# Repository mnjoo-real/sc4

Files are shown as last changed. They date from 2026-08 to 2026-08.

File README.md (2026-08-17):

# Singing capacitor — pre-experiment numerical model

## PCB ordering — start here

A validated PCB fabrication package for all 5 board variants exists under
[`pcb/`](pcb/). This section is a navigation index only — the files linked
below are the source of truth; nothing here duplicates their content.

**Start here:**
[`pcb/v0.3.1_FABRICATION_PACKAGE_SUMMARY.md`](pcb/v0.3.1_FABRICATION_PACKAGE_SUMMARY.md)

This is the top-level summary of the current PCB fabrication package and
records whether each board variant has passed the required KiCad/DRC/
Gerber/drill/visual checks.

For detailed per-board validation — including the authoritative
`READY_FOR_JLCPCB` status for each variant — see
[`pcb/FABRICATION_REVIEW.md`](pcb/FABRICATION_REVIEW.md). **Only order a
board whose entry there is marked ready.**

### The five board variants

    S90-0402
    S90-0603
    S90-0805
    W90-0603
    S0-0603

### Where the actual files are, per variant

| what | where | for |
|---|---|---|
| Editable KiCad source | `pcb/<variant>/<variant>.kicad_pcb` | opening/editing in KiCad |
| Raw Gerber + drill files | `pcb/<variant>/manufacturing/gerbers/` | inspection, not direct upload |
| **JLCPCB upload archive** | `pcb/<variant>/manufacturing/<variant>_JLCPCB_Gerber.zip` | **upload this to JLCPCB** |
| Gerber verification images | `pcb/<variant>/manufacturing/gerber_verification/` | checking the export against the design before ordering |
| KiCad 3D renders | `pcb/<variant>/renders/` | visual sanity-check, not fabrication input |

**The `*_JLCPCB_Gerber.zip` file is the file to upload to JLCPCB.** Do not
upload the `.kicad_pcb`/`.kicad_pro` source files, the PNG renders, or the
DRC/validation reports — those are for review, not fabrication input.

The five current upload archives:

- [`pcb/S90-0402/manufacturing/S90-0402_JLCPCB_Gerber.zip`](pcb/S90-0402/manufacturing/S90-0402_JLCPCB_Gerber.zip)
- [`pcb/S90-0603/manufacturing/S90-0603_JLCPCB_Gerber.zip`](pcb/S90-0603/manufacturing/S90-0603_JLCPCB_Gerber.zip)
- [`pcb/S90-0805/manufacturing/S90-0805_JLCPCB_Gerber.zip`](pcb/S90-0805/manufacturing/S90-0805_JLCPCB_Gerber.zip)
- [`pcb/W90-0603/manufacturing/W90-0603_JLCPCB_Gerber.zip`](pcb/W90-0603/manufacturing/W90-0603_JLCPCB_Gerber.zip)
- [`pcb/S0-0603/manufacturing/S0-0603_JLCPCB_Gerber.zip`](pcb/S0-0603/manufacturing/S0-0603_JLCPCB_Gerber.zip)

### Before ordering — read in this order

1. [`pcb/v0.3.1_FABRICATION_PACKAGE_SUMMARY.md`](pcb/v0.3.1_FABRICATION_PACKAGE_SUMMARY.md) — current fabrication-package summary.
2. [`pcb/FABRICATION_REVIEW.md`](pcb/FABRICATION_REVIEW.md) — detailed per-board validation, `READY_FOR_JLCPCB` status, and the Gerber/drill/render file map.
3. [`design/jlcpcb_order_settings.csv`](design/jlcpcb_order_settings.csv) — the JLCPCB fabrication options to select on the quote/order page (material, layers, thickness, copper weight, surface finish, etc.).
4. [`design/pcb_quantity_plan.csv`](design/pcb_quantity_plan.csv) — planned bare-PCB order quantities, per variant.
5. [`design/board_population_plan.csv`](design/board_population_plan.csv) — how the ordered boards are intended to be populated with MLCCs for the experiment.
6. [`design/PCB_FABRICATION_SPEC.md`](design/PCB_FABRICATION_SPEC.md) — detailed fabrication/design rationale and the common board specification.
7. [`design/PCB_CAD_ASSUMPTIONS.md`](design/PCB_CAD_ASSUMPTIONS.md) — fabrication/CAD parameters not originally fixed in v0.3.0, and the assumptions/fixes made while generating the KiCad files.

**⚠ Quantity check before the final order:** `pcb_quantity_plan.csv` is the
order-quantity source; `board_population_plan.csv` is the specimen
population source, and should be checked against it before the final
purchase. As of this writing they **do not agree for S90-0603**:
`board_population_plan.csv` calls for 15 populated S90-0603 specimens
(R×3, C1×2, C2×2, V1×2, V2×2, V3×2, N1×2), but
`pcb_quantity_plan.csv` currently plans to order only 5 S90-0603 boards.
The other four variants (S90-0402, S90-0805, W90-0603, S0-0603) agree
(5 planned = 5 needed each). Before placing the final order, verify that
the fabrication quantity plan covers the specimen population plan — this
README does not resolve that inconsistency, and the quantity was not
guessed here.

### Placing the order

1. Open `pcb/v0.3.1_FABRICATION_PACKAGE_SUMMARY.md`.
2. Confirm the desired board is marked ready in `pcb/FABRICATION_REVIEW.md`.
3. Open `design/jlcpcb_order_settings.csv`.
4. Open `design/pcb_quantity_plan.csv` (and cross-check against
   `board_population_plan.csv` per the warning above).
5. Upload that variant's `*_JLCPCB_Gerber.zip` to JLCPCB.
6. Confirm that JLCPCB correctly detects the board (outline, layer count,
   size).
7. Apply the fabrication options from `jlcpcb_order_settings.csv`.
8. Set the quantity from the current quantity plan.
9. Inspect the online Gerber preview (checklist below).
10. Only then proceed to fabrication/payment.

`design/jlcpcb_order_settings.csv` remains the source of truth for the
actual option selections — the JLCPCB UI's exact labels aren't reproduced
here.

### What to check in the JLCPCB Gerber viewer

Before paying, visually compare JLCPCB's preview against this repository's
verified artifacts and confirm, at minimum:

- board outline appears correct,
- four mounting holes are present,
- the MLCC footprint is present at the intended position,
- S90 vs. S0 orientation is visibly different where intended,
- top copper traces are present,
- there is no unexpected bottom copper,
- solder-mask openings are present over the intended pads,
- no obvious trace or outline is missing.

Reference images for this comparison:

- `pcb/<variant>/manufacturing/gerber_verification/` — most relevant for
  fabrication inspection, since these are rendered directly from the
  exported Gerbers:
  `<variant>_composite_top.png`, `<variant>_top_copper.png`,
  `<variant>_solder_mask.png`, `<variant>_silkscreen.png`,
  `<variant>_edge_cuts.png`
- `pcb/<variant>/renders/` — real KiCad top/bottom/perspective 3D renders
  (useful, but decorative relative to the Gerber-verification images above)
- [`pcb/PCB_5_VARIANT_COMPARISON.png`](pcb/PCB_5_VARIANT_COMPARISON.png) — all five variants at the same scale, for a quick overview

### Bare PCB vs. assembly

The `*_JLCPCB_Gerber.zip` files are **PCB fabrication files only**.
Uploading one orders a **bare PCB** — MLCC assembly is **not** included.
See [`design/board_population_plan.csv`](design/board_population_plan.csv)
for the intended capacitor population per board. Assembly (PCBA) is a
separate deliverable, not covered by this package.

### Directory map

```
pcb/
├── v0.3.1_FABRICATION_PACKAGE_SUMMARY.md
├── FABRICATION_REVIEW.md
├── PCB_5_VARIANT_COMPARISON.png
├── S90-0402/
│   ├── S90-0402.kicad_pcb
│   ├── manufacturing/
│   │   ├── S90-0402_JLCPCB_Gerber.zip   <- upload this to JLCPCB
│   │   ├── gerbers/
│   │   ├── drc_report.txt
│   │   ├── drill_report.txt
│   │   └── gerber_verification/
│   └── renders/
├── S90-0603/
├── S90-0805/
├── W90-0603/
└── S0-0603/
```

```
design/
├── jlcpcb_order_settings.csv
├── pcb_quantity_plan.csv
├── board_population_plan.csv
├── PCB_FABRICATION_SPEC.md
└── PCB_CAD_ASSUMPTIONS.md
```

---

A lightweight simulation for planning a *singing capacitor* experiment before
ordering the PCB and MLCCs.

The goal is **not** to predict the exact sound level of a commercial capacitor.
Instead, the model is used to decide:

- what PCB size and thickness to order,
- where to place the MLCC on the PCB,
- which orientation to use,
- what frequency range to sweep,
- and which conditions should produce a strong or weak vibration response.

The model deliberately keeps only the physics needed for those design choices.

---

## 1. The physics being modelled

A Class-II ceramic MLCC such as X5R or X7R deforms when an electric field is
applied. The first-order electromechanical model is

    S = dE + M E²

where `S` is strain, `d` is the piezoelectric coefficient, `M` is the
electrostrictive coefficient, and `E` is the electric field.

For

    E(t) = E_DC + E_AC cos(ωt)

the strain contains two important vibration components:

    A₁ cos(ωt),        A₁ = (d + 2 M E_DC) E_AC
    A₂ cos(2ωt),       A₂ = ½ M E_AC²

so an electrical excitation at frequency `f` can mechanically excite the PCB
at both

    f          fundamental
    2f         second harmonic

The second harmonic is important because it can hit a PCB resonance even when
the electrical excitation frequency itself does not.

For the first version of the simulation, the exact `d` and `M` of a commercial
MLCC are **not required**. The capacitor is treated as a relative vibration
source with configurable strengths at `f` and `2f`.

### PCB resonance

The PCB is approximated as a rectangular thin plate.

Its bending rigidity is

    D = E h³ / [12(1 − ν²)]

where `E` is the effective Young's modulus of the PCB, `h` is PCB thickness,
and `ν` is Poisson's ratio.

For a simply supported rectangular plate with length `a` and width `b`,

    φ_mn(x,y) = sin(mπx/a) sin(nπy/b)

and the natural frequencies are

    ω_mn = π² √(D / ρh) · (m²/a² + n²/b²)

    f_mn = ω_mn / 2π

This is not intended to reproduce a real clamped PCB exactly. It is sufficient
for finding the main trends:

- a larger PCB gives lower resonant frequencies,
- a thicker PCB gives higher resonant frequencies,
- different MLCC positions couple differently to each mode.

### MLCC position and orientation

The MLCC does not excite every PCB mode equally.

For a simple point-force source,

    coupling ∝ φ_mn(x_c, y_c)

so a capacitor near a modal antinode excites that mode strongly, while one near
a node excites it weakly.

The soldered MLCC also acts approximately like a small force couple / moment.
For that case the coupling is related to the slope of the mode shape:

    x-oriented MLCC:  coupling ∝ ∂φ_mn/∂x
    y-oriented MLCC:  coupling ∝ ∂φ_mn/∂y

This is why rotating the same MLCC by 90° can change the PCB vibration.

The simulation therefore focuses on the chain

    voltage
      ↓
    relative MLCC source at f and 2f
      ↓
    PCB mode coupling
      ↓
    PCB vibration response

rather than trying to model every internal ceramic layer.

---

## 2. What the code actually does

### MLCC source (`source.py`)

The capacitor is represented by two harmonic source components:

    source_f  = C₁ · A₁
    source_2f = C₂ · A₂

For the initial model, `C₁` and `C₂` are simply configurable scale factors.

If real electromechanical coefficients are unavailable, the code can instead
use normalized source strengths such as

    source_f  = 1
    source_2f = r_harmonic

so PCB design can be studied independently of the uncertain absolute MLCC
vibration amplitude.

The important output is therefore **relative response**, not absolute SPL.

### PCB (`plate.py`)

The PCB is an isotropic rectangular thin plate with configurable

    length
    width
    thickness
    Young's modulus
    density
    Poisson ratio
    damping

The code computes the first several `(m,n)` modes analytically.

The default reference geometry is the one used in Kim et al. (2019):

    100 mm × 40 mm × 1.0 mm

This is only a baseline. The simulation sweeps several nearby geometries to find
a board that has clear resonances in the experimental frequency range.

### Coupling (`coupling.py`)

For each candidate MLCC position and orientation, the code evaluates how
strongly the source couples to every PCB mode.

The main scan is

    x/a = 0.20, 0.35, 0.50, 0.65, 0.80
    y/b = 0.25, 0.50, 0.75
    orientation = 0°, 90°

This produces both

- a **high-coupling position** for a clear singing-capacitor demonstration,
- and a **low-coupling position** that can be used as a control.

### Frequency response (`response.py`)

Each PCB mode is treated as a damped harmonic oscillator:

    q_n(ω) =
        Q_n /
        [m_n(ω_n² − ω² + i 2ζ_n ω_n ω)]

The modal responses are summed to obtain relative PCB displacement and velocity.

The simulation evaluates the response at both

    f
    2f

for each electrical excitation frequency.

The main plotted quantity is PCB velocity amplitude, used only as a
**vibration / acoustic-noise proxy**.

No acoustic radiation model is included.

### Sweep (`run_sweep.py`)

The first design sweep varies

    PCB length       60, 80, 100 mm
    PCB width        30, 40 mm
    PCB thickness    0.8, 1.0, 1.6 mm

and scans excitation frequencies over

    200–3000 Hz

with a coarse step first, followed by a finer scan near predicted resonances.

After the PCB geometry is selected, the code scans MLCC position and orientation.

The simulation is therefore used in this order:

    1. choose PCB geometry
    2. find PCB resonances
    3. choose MLCC position
    4. compare 0° and 90° orientation
    5. choose useful excitation frequencies
    6. define strong-response and weak-response experimental conditions

---

## 3. Validation (`test_model.py`)

The model only needs simple checks because it is an experiment-design tool, not
a high-fidelity FEM solver.

| check | expected result |
|---|---|
| increasing PCB length | resonant frequencies decrease |
| increasing PCB thickness | resonant frequencies increase |
| mode shape at supported edge | approximately zero |
| MLCC placed at a modal node | weak point-force coupling |
| MLCC placed at an antinode | strong point-force coupling |
| rotate MLCC by 90° | x/y moment coupling changes |
| increase damping | resonance peak becomes lower and broader |
| electrostrictive source | response can appear at `2f` |

The code should also reproduce the analytical strain amplitudes

    A₁ = (d + 2 M E_DC) E_AC
    A₂ = ½ M E_AC²

for a synthetic test case.

Synthetic coefficients are used only to check the equations; they must not be
presented as properties of a real commercial MLCC.

---

## 4. Outputs

### `fig1_modes.png`

The first PCB mode shapes and their natural frequencies for the baseline

    100 × 40 × 1 mm

board.

This shows which PCB modes lie inside the planned excitation range.

### `fig2_geometry_sweep.png`

Predicted resonant frequencies for different PCB sizes and thicknesses.

This is the main figure for deciding **which PCB to order**.

A useful board should have:

- at least a few resonances inside the measurable frequency range,
- resonances separated enough to identify experimentally,
- and no extreme sensitivity to small geometry changes.

### `fig3_frequency_response.png`

Relative PCB vibration versus electrical excitation frequency.

Both mechanical components are shown:

    response at f
    response at 2f

A strong peak occurs when either `f` or `2f` approaches a PCB resonance.

This figure determines which frequency ranges should be scanned more densely in
the real experiment.

### `fig4_position_map.png`

Heatmap of predicted vibration versus MLCC position.

This is used to choose

- one high-response capacitor location,
- one low-response control location.

### `fig5_orientation.png`

Comparison of the same MLCC position at

    0°
    90°

to determine whether orientation should be included as an experimental variable.

### `recommended_setup.csv`

Final summary produced by the sweep:

| parameter | recommended value |
|---|---|
| PCB length | simulation result |
| PCB width | simulation result |
| PCB thickness | simulation result |
| MLCC x-position | simulation result |
| MLCC y-position | simulation result |
| MLCC orientation | simulation result |
| main frequency range | simulation result |
| resonance frequencies | simulation result |
| strong-response condition | simulation result |
| control condition | simulation result |

The code should not fill this table with hard-coded recommendations. Values are
written only after the sweep has been run.

---

## 5. Running it

```bash
pip install numpy scipy matplotlib pandas

python test_model.py
python run_modes.py
python run_sweep.py geometry
python run_sweep.py position
python run_sweep.py all
```

All figures and tables are written to

```text
out/
```

Suggested repository structure:

```text
singing-capacitor/
│
├── README.md
├── model.py
├── source.py
├── plate.py
├── coupling.py
├── response.py
├── test_model.py
├── run_modes.py
├── run_sweep.py
└── out/
```

The main parameters should be collected in one dataclass:

```python
from dataclasses import dataclass

@dataclass
class Params:
    pcb_L: float = 0.100
    pcb_W: float = 0.040
    pcb_h: float = 0.001

    E_pcb: float = 20e9
    rho_pcb: float = 1850.0
    nu_pcb: float = 0.13
    damping: float = 0.02

    mlcc_x_frac: float = 0.50
    mlcc_y_frac: float = 0.50
    orientation_deg: float = 0.0

    f_min: float = 200.0
    f_max: float = 3000.0
```

The exact effective FR-4 material constants are uncertain, so these values are
configuration parameters rather than fixed physical truths.

---

## 6. Known limitations — worth stating in a report

* The PCB is an **isotropic simply supported thin plate**. A real FR-4 PCB is
  anisotropic and the experimental bolts/clamps change its natural frequencies.
  The model should therefore be used for geometry selection and qualitative
  trends, not exact resonance prediction.

* The MLCC is represented as a **lumped harmonic source**, not as hundreds of
  dielectric and electrode layers. This is deliberate: the purpose is to choose
  the experimental PCB and setup before the exact commercial MLCC properties
  are known.

* Exact piezoelectric and electrostrictive coefficients of commercial MLCCs are
  usually unavailable. Unless experimentally measured values are supplied, the
  simulation should compare **relative source amplitudes**, not claim absolute
  capacitor vibration.

* Solder geometry is not explicitly modelled. Its effect is absorbed into the
  equivalent source / moment coupling.

* The first model does not calculate sound pressure. PCB velocity is used as a
  proxy for how strongly the board is likely to radiate sound.

* Absolute resonance frequencies will shift after the real PCB is manufactured
  and mounted. After the first PCB is measured, the effective material and
  damping parameters can be calibrated and the simulation rerun.

---

## 7. What this simulation must decide before ordering

The model is successful if it answers these practical questions:

1. Should the PCB be approximately `60`, `80`, or `100 mm` long?
2. Should its thickness be `0.8`, `1.0`, or `1.6 mm`?
3. Which resonances fall inside the planned excitation range?
4. Where should the MLCC be soldered for a strong response?
5. Where should a control MLCC be soldered for a weak response?
6. Does rotating the MLCC by 90° produce a useful difference?
7. Which electrical frequencies should be scanned densely in the real test?
8. Is the response dominated by the fundamental `f`, the second harmonic `2f`,
   or both?

Once these are answered, the PCB can be ordered and the detailed MLCC
comparison can be designed around the selected board.

The key principle is:

    keep the model only as complicated as necessary
    to make the experimental setup decision.

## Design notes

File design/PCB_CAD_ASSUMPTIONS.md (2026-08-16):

# PCB CAD assumptions — v0.3.1

This lists every fabrication parameter that v0.3.0 (`design/PCB_FABRICATION_SPEC.md`,
`design/pcb_variants.csv`, `design/pcb_coordinates.csv`) left unspecified,
and the assumption `pcb/generate_pcb.py` used to fill it in, per the task
instruction: *"do not silently treat a new assumption as an existing v0.3.0
decision."* Each item below is tagged **[v0.3.0, existing]** if it was
already fixed by earlier design docs, or **[v0.3.1, new assumption]** if
this stage introduced it.

No inconsistency was found between the task brief's stated common
specification / MLCC placement table and `pcb_variants.csv` /
`pcb_coordinates.csv` — they match exactly, so nothing was silently
changed.

## Environment constraint (read first)

**KiCad is not installed in this environment** (checked: no `kicad-cli` on
PATH, no `pcbnew` Python module, no `/Applications/KiCad*`, not found via
`brew`). This affects every assumption below: none of these `.kicad_pcb`
files have been opened, parsed, or DRC'd by real KiCad. See
`pcb/FABRICATION_REVIEW.md` for exactly what was and wasn't possible to
verify as a result.

## 1. Edge interface pad **center coordinates** — existing, reused

**[v0.3.0, existing]**. `PCB_FABRICATION_SPEC.md` section 5 already gives a
"suggested reference pad row" at x=5mm, y = 12.5 / 17.5 / 22.5 / 27.5 mm for
DRIVE+ / SENSE+ / SENSE- / DRIVE- respectively (marked "to be confirmed in
EDA, not final" — but it is a value, not a gap). This implementation treats
those coordinates as the thing to implement, per the task's own instruction
that its preferred default applies only *"if no value is already
specified."* The generator's `EDGE_PAD_X` / `EDGE_PADS` constants match this
table exactly.

## 2. Edge interface pad **shape and diameter** — new assumption

**[v0.3.1, new assumption]**. v0.3.0-C fixed the pad *centers* but never a
shape or size. This was genuinely open, so the task's stated preferred
default was used: **round, 2.5 mm diameter**, exposed copper (ENIG) with no
solder-mask covering, no paste layer (hand-soldered wire lead, not a
reflow part). Implemented as `EdgeContact_2.5mm_Round` in
`pcb/SC4.pretty/`.

## 3. Exact trace routing geometry — new assumption

**[v0.3.1, new assumption]**. v0.3.0-C fixed trace *widths* (0.5 mm drive,
0.2 mm sense) and the *topological* rule (SENSE traces must originate
directly at the MLCC pad copper, not tap the DRIVE trace) but never a
routed path. This implementation uses the simplest routing that satisfies
that rule without producing an unintended short:

- Each of the 4 nets gets its own dedicated staging x-lane (`mlcc_x - 8`
  through `mlcc_x - 5`, one per net) so no two different-net segments ever
  run parallel/collinear.
- For 90 deg boards (S90-*, W90-0603), each trace is a simple 3-segment
  L-route: edge pad -> its staging lane -> the target MLCC pad's row ->
  straight into the pad. No detour is needed because the two MLCC pads
  differ only in y, and each net's staging lane already sits at a distinct
  y before converging.
- For the 0 deg board (S0-0603), the two MLCC pads differ only in x, so a
  trace headed for the farther pad would otherwise have to cross straight
  through the nearer pad's copper. Only for this case, the SENSE-/DRIVE-
  pair detours above the nearer pad (`mlcc_y + pad_height/2 + 0.3 mm`
  clearance) before dropping onto the far pad. This is the "extra
  complexity only where necessary" the task asked for — the 90 deg boards
  do not need it.
- `pcb/validate_pcb.py` checks geometrically that no two different-net
  F.Cu segments touch or cross anywhere except at their one legitimate
  shared point (the MLCC pad itself).

## 4. DRIVE+/SENSE+ and DRIVE-/SENSE- net topology — new assumption, explicit trade-off

**[v0.3.1, new assumption]**. This is the most consequential CAD decision
in this package, so it's called out on its own.

A 4-wire/Kelvin connection means DRIVE+ and SENSE+ are, by design,
electrically the *same node* — they are both wired straight to the MLCC's
+ terminal with nothing in between; that's what makes it "4-wire" (the
DRIVE path carries current, the SENSE path carries ~none, so IR drop in the
DRIVE trace doesn't corrupt what SENSE reads). A PCB tool's "net" is
defined as a connectivity group, so representing DRIVE+ and SENSE+ as two
different net objects that are also physically joined at the MLCC pad is,
strictly, the same thing electrically — the question is only how to encode
it in KiCad's file format.

KiCad has a purpose-built feature for exactly this ("net ties": a
footprint attribute, `net_tie_pad_groups`, that lets two named nets touch
at one defined point without DRC treating it as a short elsewhere). That
would let this design keep 4 distinctly-named nets. **It was not used
here**, because its exact file-format syntax could not be verified without
a working KiCad installation, and getting it wrong risks producing a file
that fails to parse in KiCad at all — a worse outcome than a
syntactically-safe simplification.

Instead: **DRIVE+ and SENSE+ share one KiCad net (`DRIVE_SENSE_PLUS`), and
DRIVE- and SENSE- share one KiCad net (`DRIVE_SENSE_MINUS`)**. This is
electrically identical to the intended Kelvin topology. The 4 external
pads remain individually and correctly labeled (`DRIVE+`, `SENSE+`,
`SENSE-`, `DRIVE-` as each edge-contact footprint's reference designator)
and are routed as 4 physically separate, non-touching copper traces (see
item 3) — only the *net name* is merged, not the copper layout.

**Consequence for the validation requirement** "all four interface nets
reach the intended MLCC terminal": this is verified as *connectivity*
(each of the 4 labeled pads reaches the correct terminal's copper), not as
4 distinct KiCad net objects — there are 2. If true 4-distinct-net
modeling via KiCad net ties is wanted, that is a follow-up task for someone
with a working KiCad installation to implement and verify; it would not
change any board geometry, only the netlist representation.

## 5. Which MLCC pad is the "+" terminal — new assumption

**[v0.3.1, new assumption]**. The MLCC is a non-polarized ceramic capacitor
— "+"/"-" is a labeling convention for this design, not a real polarity.
Convention used: for 90 deg boards, the pad at the *smaller* y (closer to
the DRIVE+/SENSE+ side of the edge row) is "+"; for the 0 deg board, the
pad at the *smaller* x (nearer the edge, i.e. pad1 in `pcb_coordinates.csv`)
is "+". This keeps routing short and simple; it has no effect on the
experiment (the model treats the MLCC as an unpolarized source).

## 6. MLCC footprint pad size / pitch — existing, reused

**[v0.3.0, existing]**. Taken directly from `PCB_FABRICATION_SPEC.md`
section 4's nominal IPC-7351 table (0402: 0.6x0.6mm pads / 1.0mm pitch;
0603: 0.9x1.0mm / 1.6mm; 0805: 1.2x1.45mm / 1.9mm) and
`pcb_coordinates.csv`'s computed pad centers. Not re-derived here.

## 7. Silkscreen content and placement — new assumption, deliberately conservative

**[v0.3.1, new assumption]**. `PCB_FABRICATION_SPEC.md` section 7 permits
*only* "board/variant identification silkscreen (e.g. 'S90-0603', a rev
letter)" in the edge strip, and forbids non-essential silkscreen in the
active region entirely. This implementation:

- Prints only the variant name (e.g. `S90-0603`) as silkscreen text, at a
  single position (x=5, y=31mm) chosen to clear both the edge-pad column
  (which ends at y=27.5+1.25=28.75mm) and the top mounting hole's keepout
  (which starts at y=35-1.6=33.4mm) — this position is identical across
  all 5 variants since the edge row geometry doesn't vary by variant.
- Does **not** silkscreen individual pad-function labels (DRIVE+, SENSE+,
  etc.) next to each pad, even though there was room — the spec only
  explicitly allows variant/rev identification, and adding more was judged
  to be overstepping v0.3.0-C rather than implementing it.
- Hides the reference/value silkscreen KiCad normally auto-generates for
  every footprint (MLCC and all 4 mounting holes), since two of the four
  mounting holes (at x=95mm) and the MLCC itself sit in the active region
  (x>15mm) where that silkscreen would be disallowed.

## 8. Board stackup / manufacturing defaults not otherwise specified

**[v0.3.1, new assumption]**, using generic, non-consequential defaults
since v0.3.0 explicitly left these to "manufacturer default" /
open-at-order-time (`jlcpcb_order_settings.csv`):

- Solder-mask-to-copper clearance: 0.05 mm (generic default).
- 2-layer stackup with F.Cu/B.Cu both defined (required by the file
  format) but zero copper features ever placed on B.Cu.

## 9. Coordinate system note (not an assumption about the design, a KiCad-mechanics note)

The design docs use origin = bottom-left, x/y both increasing "up/right".
KiCad's own on-screen Y axis increases downward by default. This
implementation stores every coordinate's numeric value exactly as given in
`pcb_coordinates.csv` / the task brief as KiCad's literal (x, y) — it does
not attempt to flip anything to "look" correct on screen. This has no
effect on manufactured geometry (hole spacing, MLCC-to-hole relationships,
and silkscreen orientation are all self-consistent within the file), but
means a human opening these files in KiCad should confirm orientation by
reading the printed variant-ID silkscreen text and cross-checking numeric
coordinates (KiCad's Properties panel), not by assuming screen "up" means
larger y.

## Summary table

| item | status |
|---|---|
| Board outline, thickness, layer count, copper weight, finish | v0.3.0, existing |
| Mounting hole coordinates and diameter | v0.3.0, existing |
| MLCC center coordinates and orientation, per variant | v0.3.0, existing |
| MLCC footprint pad size/pitch, per package | v0.3.0, existing |
| Edge interface pad center coordinates | v0.3.0, existing |
| Drive/sense trace widths | v0.3.0, existing |
| Edge interface pad shape/diameter | v0.3.1, new (task default: round 2.5mm) |
| Exact trace routing path | v0.3.1, new |
| DRIVE+/SENSE+ and DRIVE-/SENSE- net topology (merged vs. net-tie) | v0.3.1, new, explicit trade-off |
| "+"/"-" terminal labeling convention | v0.3.1, new (arbitrary, no experimental effect) |
| Silkscreen content/placement | v0.3.1, new, deliberately minimal |
| Solder mask clearance and other fab-default values | v0.3.1, new, non-consequential |

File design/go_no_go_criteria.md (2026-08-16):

# Go/no-go criteria — v0.3.0-E

**Placement**: after Phase 1 (reference position/orientation validation),
before Phase 2 (start of the full capacitor-property dataset). See
`experiment_phases.md`.

## The three checks

Per the design brief: do not proceed to the full capacitor-property dataset
(Phases 2-8) if there is no reproducible PCB resonance, no reproducible
position effect, and no reproducible orientation effect.

**Interpretation note**: this design treats the three checks as
independently gating — a "no-go" on *any one* of them is sufficient to stop
(standard practice for a validation gate: an experiment shouldn't proceed to
a full comparison campaign if any one of its foundational assumptions
hasn't checked out, even if the other two look fine). If a stricter reading
was intended (stop only if *all three* simultaneously fail), that changes
the gate significantly and should be corrected explicitly — flagging it here
rather than silently picking one.

### 1. Reproducible PCB resonance

- Phase 0 (S90-0603-R-01) establishes fr1, fr2, fr3 from a full broad sweep.
- Phase 1 does not repeat a full broad sweep on every other specimen (see
  `experiment_phases.md`). Instead, treat resonance as reproducible if the
  other two S90-0603-R specimens (R-02, R-03) show a clear, elevated
  acoustic response at or near fr1, fr2, and fr3 (the same set points
  already being measured in Phase 1's standard six-frequency set) relative
  to that session's background-noise floor.
- **Suggested check** (adjust to the noise floor actually observed —
  this number is a starting point, not a value given in the design brief):
  peak acoustic amplitude at each of fr1/fr2/fr3 is at least ~6 dB above
  the session's background-noise recording, for both R-02 and R-03.
- **No-go** if R-02 or R-03 shows no such elevated response at the expected
  set points (suggesting the resonance seen on R-01 was a one-off, not a
  property of the board design).

### 2. Reproducible position effect

- Compare S90-0603-R-01/02/03 (strong position) against
  W90-0603-R-01/02/03 (weak/control position) at the standard condition
  (0.10 V_peak, 0 V, standard six-frequency set).
- **Go** if S90 response is consistently higher than W90 response across the
  replicate pairs (matching the predicted ~4.9x strong/control ratio
  direction from `out/final_pcb_recommendation.txt` — the magnitude is a
  simulation guide only, not a pass/fail threshold; only the *direction and
  consistency* of the effect is being checked here).
- **No-go** if the S90/W90 difference is inconsistent across replicates or
  absent.

### 3. Reproducible orientation effect

- Compare S90-0603-R-01/02/03 (90 deg) against S0-0603-R-01/02/03 (0 deg,
  same position) at the standard condition.
- **Go** if S90 response is consistently higher than S0 response across the
  replicate pairs (matching the predicted ~1.8x orientation ratio direction
  from `out/final_pcb_recommendation.txt`, direction/consistency only, not a
  magnitude threshold).
- **No-go** if the S90/S0 difference is inconsistent across replicates or
  absent.

## Decision

- **Go**: all three checks pass. Proceed to Phase 2 onward per
  `experiment_phases.md` / `final_experiment_matrix.csv`.
- **No-go**: any check fails. Do not proceed to Phases 2-8. Instead:
  1. Re-check the electrical setup against `ELECTRICAL_MEASUREMENT_SETUP.md`
     (grounding, Kelvin sense wiring, mic position per
     `measurement_geometry.csv`).
  2. Re-check the physical mounting against `PCB_FABRICATION_SPEC.md`
     section 3 (compliant corner standoffs, not rigid clamping).
  3. Re-run Phase 1 once the above are confirmed.
  4. If still no-go after a confirmed re-run, this is a finding about the
     reduced-order model's applicability (README.md section 6, "Known
     limitations"), not just a setup error, and should be reported as such
     before any further boards/capacitors are purchased or tested.

## What this gate does not check

This gate validates the *board-level* behavior (resonance existence,
position sensitivity, orientation sensitivity) using the reference
capacitor only. It does not validate any capacitor-property comparison
(package, capacitance, rated voltage, dielectric) — those are exactly what
Phases 2-6 are for, and are only meaningful once this gate has passed.

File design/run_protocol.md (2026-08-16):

# Run protocol — v0.3.0-D

Operating procedure for a measurement session, built on
`ELECTRICAL_MEASUREMENT_SETUP.md`. Follow this in order.

## 1. Before any session

- [ ] Confirm grounding: generator ground = DRIVE- = oscilloscope reference.
      Protective earth intact on every mains-powered instrument — do not
      float the scope (`ELECTRICAL_MEASUREMENT_SETUP.md` section 8).
- [ ] Confirm the board under test and the capacitor mounted on it against
      `experiment_matrix_template.csv` / `pcb_coordinates.csv`.
- [ ] Confirm the capacitor's rated voltage is on hand, and pre-check the
      voltage budget for every level combination you intend to run:
      `|Vdc| + Vac_peak <= rated voltage`. Cross out any combination that
      fails this before starting.
- [ ] Position the microphone per `measurement_geometry.csv` (100 mm above
      PCB center, pointing down at the board). Do not reposition it between
      runs or between board variants within a session.
- [ ] If this is a commissioning session using the 0.1 ohm shunt, treat it
      as a separate step per `ELECTRICAL_MEASUREMENT_SETUP.md` section 9 —
      do not leave the shunt in place for normal data-collection runs.

## 2. Session start — background noise

- [ ] With the function generator **off**, record at least **10 s** of
      background noise from the microphone.
- [ ] Save it and note its `background_reference_id` (see `data_schema.csv`)
      — every acoustic amplitude recorded in this session is compared
      against this noise floor.

## 3. Stage 1 — broad resonance search (per board)

For the board under test, run both bands from `excitation_plan.csv`:

| band | range | step |
|---|---|---|
| low | 200-3000 Hz | 25 Hz |
| high | 3000-20000 Hz | 100 Hz |

- Start at the lowest excitation level (0.05 V_peak, Vdc=0). Escalate only
  if the microphone signal-to-noise is insufficient to see peaks — and if
  you do escalate, re-check the `I_peak` estimate (section 3 of
  `ELECTRICAL_MEASUREMENT_SETUP.md`) stays approximately <= 25 mA where
  practical, and re-check the voltage budget.
- At each frequency point, follow the per-frequency-point procedure
  (section 5 below).
- Watch for the amplifier-fallback triggers (amplitude collapse, clipping,
  current-limit behavior) throughout — see section 6 of
  `ELECTRICAL_MEASUREMENT_SETUP.md`. If observed, stop and flag for review;
  do not proceed to add an amplifier without that review.
- After the sweep, identify candidate resonances `fr` from the recorded
  acoustic amplitude vs. frequency curve. This stage is for locating
  resonances only — do not draw capacitor-comparison conclusions from it.

## 4. Stage 2 — dense scan (per measured resonance, per board)

For each `fr` identified in Stage 1, on that same board:

- scan `fr - 100 Hz` to `fr + 100 Hz`, step 2-5 Hz,
- scan `fr/2 - 100 Hz` to `fr/2 + 100 Hz`, step 2-5 Hz (2f electrostrictive
  excitation check),
- at whatever excitation level(s) the current phase of testing calls for
  (see `experiment_matrix_template.csv` for the planned reference-vs-
  candidate schedule), re-checking the voltage budget and `I_peak` guidance
  for each level used.

## 5. Per-frequency-point procedure

At every individual frequency point in Stage 1 or Stage 2:

1. Set the condition (frequency, Vac_peak, Vdc).
2. Settle **0.5 s**.
3. Record **2.0 s**.
4. Save the raw microphone waveform.
5. Extract the measured DUT voltage from the SENSE+/SENSE- capture
   (`V_DUT = CH1 - CH2`, or CH1 alone if only one channel is captured —
   see `ELECTRICAL_MEASUREMENT_SETUP.md` section 1).
6. Extract acoustic amplitude at `f`.
7. Extract acoustic amplitude at `2f`.
8. Log the row per `data_schema.csv`.

## 6. Test order across boards and capacitors

Per `pcb_variants.md` / `PRE_PURCHASE_DESIGN.md`:

1. Reference MLCC on **S90 (all 3 footprints), W90-0603, S0-0603** — Stage 1
   then Stage 2 on each — to validate the simulated position and
   orientation effects before testing anything else.
2. Only after that validation, test candidate capacitors (`TBD-1`,
   `TBD-2`, ...) primarily on the **S90** variants (Stage 1 then Stage 2
   each).

## 7. After each session

- [ ] Confirm every raw waveform file referenced in the session's log rows
      actually exists and is non-empty.
- [ ] Confirm the background-noise recording for the session is saved and
      linked (`background_reference_id`).
- [ ] Note in `notes` any deviation from this protocol (extra settle time,
      re-runs, amplifier-fallback flags, shunt commissioning steps, etc.).

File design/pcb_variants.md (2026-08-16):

# PCB variants — v0.3.0 pre-purchase design

This document defines the three physical PCB variants to order, based on the
v0.2.0 simulation result (`out/final_pcb_recommendation.txt`,
`out/pcb_candidate_comparison.csv`):

- PCB outline: **100 mm x 40 mm**, thickness **1.0 mm**
- predicted strong position: `x/a=0.50, y/b=0.25`, orientation 90 deg
- predicted weak/control position: `x/a=0.20, y/b=0.50`, orientation 90 deg
- predicted strong/control response ratio: **4.9x**
- predicted 0 deg / 90 deg orientation response ratio: **1.8x** (90 deg stronger)
- predicted resonances: **1090, 1541, 2293 Hz** (modes (1,1), (2,1), (3,1))

These numbers come from the existing reduced-order model (isotropic
simply-supported thin plate + lumped MLCC source, see `README.md`). They are
**guides for where to place the MLCC and which frequencies to scan first**,
not exact experimental predictions. The real resonances, once clamped/mounted
and manufactured, will shift from these values — see "Known limitations" in
`README.md` section 6.

## Common specification (all three variants)

All three boards share everything except MLCC placement and orientation, so
that any measured difference between boards can be attributed to position /
orientation rather than to an uncontrolled difference in the board itself.

- **Outline**: 100 mm x 40 mm rectangular PCB.
- **Thickness**: 1.0 mm PCB stack-up (spec thickness; actual manufactured
  thickness should be recorded per board once received, since resonances
  depend on it).
- **Mounting scheme**: support the board at its four corners on compliant
  (soft rubber / foam) point standoffs, not rigid clamps or screws directly
  into the copper. A compliant point support at the corners approximates the
  simply-supported boundary condition assumed by the model far better than a
  rigid clamp, which stiffens the edges and shifts resonances upward
  unpredictably. Mount all three boards identically.
- **Electrical connection strategy**: bring drive leads in at one short edge
  of the board, away from the MLCC, using thin flexible lead wire
  (30-32 AWG). Anchor the wires near the edge with a small dab of adhesive
  or tape for strain relief. This keeps the added mass/stiffness/damping of
  the wiring away from the vibrating region, per the "wires near the edge,
  not near the MLCC" principle below.
- **Test-pad strategy**: provide two dedicated test pads immediately at the
  MLCC solder joints (Kelvin-style, i.e. separate from the current-carrying
  drive pads where practical) for direct oscilloscope probing of the actual
  DUT voltage. Do not rely on the function-generator's displayed voltage —
  see the "DUT voltage" principle below.

## Variant S90 — primary strong-response board

- MLCC center: **x = 50 mm, y = 10 mm** (`x/a=0.50, y/b=0.25`)
- Orientation: **90 deg**
- Purpose: the primary board for the singing-capacitor demonstration and for
  comparing candidate MLCCs. Predicted to produce the strongest vibration
  response of the three variants.
- This is the board that receives the full excitation sweep (broad, then
  dense) and that every capacitor-property candidate is tested on.

## Variant W90 — position-control board

- MLCC center: **x = 20 mm, y = 20 mm** (`x/a=0.20, y/b=0.50`)
- Orientation: **90 deg**
- Purpose: same orientation as S90, but placed near a predicted low-coupling
  position. Used with the reference MLCC only, to validate that the
  simulated ~4.9x strong/control contrast actually shows up experimentally.
  A "weak" board that still sings strongly would indicate the coupling
  model, not just its absolute predictions, needs revisiting.

## Variant S0 — orientation-control board

- MLCC center: **x = 50 mm, y = 10 mm** (`x/a=0.50, y/b=0.25`) — identical
  position to S90
- Orientation: **0 deg**
- Purpose: isolates the effect of MLCC orientation from position, holding
  position fixed at the S90 site. Used with the reference MLCC only, to
  validate the simulated ~1.8x orientation contrast (90 deg stronger than
  0 deg at this position).

See `pcb_coordinates.csv` for the machine-readable version of this table.

## Experimental principles (apply to all variants and all runs)

- **Wire placement**: external wires attach near the PCB edge, not near the
  vibrating MLCC — added mass, stiffness, and damping from the wiring would
  otherwise distort the very vibration being measured.
- **DUT voltage**: measure the voltage directly across the capacitor (at the
  dedicated test pads), not the function-generator's dial/display setting.
  Cable impedance, contact resistance, and the capacitor's own reactive
  loading mean the function-generator setting is not necessarily the actual
  MLCC voltage.
- **Drive current**: account for the capacitive drive current
  `I_peak = 2 * pi * f * C * V_peak`. This current rises linearly with
  frequency and with the MLCC's capacitance, and can be substantial at the
  top of the swept range for a large-capacitance MLCC — check it against the
  function generator's/amplifier's output current limit before driving at
  the higher end of the 200-3000 Hz range or at high V_peak.
- **Sweep order**: first perform a broad experimental frequency sweep
  (200-3000 Hz) to find the actual PCB resonances, since the simulated
  1090/1541/2293 Hz values are guides only. Then perform dense sweeps
  centered on the measured resonances, and separately around half those
  frequencies, to test for possible 2f electrostrictive excitation.
- **Reference vs. candidate testing**: use one reference MLCC on S90, W90,
  and S0 to validate the simulated position and orientation effects. Test
  all other capacitor-property candidates primarily on S90, once the
  reference measurements confirm the board behaves as predicted.
- **No part numbers yet**: candidate capacitors are referred to only as
  placeholders (e.g. `TBD-1`, `TBD-2`) until the board-level behavior above
  has been validated experimentally. Do not commit to specific commercial
  MLCC part numbers at this stage.

See `PRE_PURCHASE_DESIGN.md` for the full pre-purchase rationale and
`excitation_plan.csv` / `experiment_matrix_template.csv` for the runnable
sweep and logging plan.

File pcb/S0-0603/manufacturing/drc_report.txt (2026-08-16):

** Drc report for S0-0603.kicad_pcb **
** Created on 2026-08-16T16:13:48 **
** Report includes: Errors, Warnings, Exclusions **

** Found 5 DRC violations **
[lib_footprint_mismatch]: 풋프린트 'C_0603_Local'이(가) 라이브러리 'SC4'의 사본과 일치하지 않습니다
    Local override; warning
    @(50.0000 mm, 10.0000 mm): 풋프린트 MLCC1
[lib_footprint_mismatch]: 풋프린트 'EdgeContact_2.5mm_Round'이(가) 라이브러리 'SC4'의 사본과 일치하지 않습니다
    Local override; warning
    @(5.0000 mm, 12.5000 mm): 풋프린트 DRIVE+
[lib_footprint_mismatch]: 풋프린트 'EdgeContact_2.5mm_Round'이(가) 라이브러리 'SC4'의 사본과 일치하지 않습니다
    Local override; warning
    @(5.0000 mm, 17.5000 mm): 풋프린트 SENSE+
[lib_footprint_mismatch]: 풋프린트 'EdgeContact_2.5mm_Round'이(가) 라이브러리 'SC4'의 사본과 일치하지 않습니다
    Local override; warning
    @(5.0000 mm, 22.5000 mm): 풋프린트 SENSE-
[lib_footprint_mismatch]: 풋프린트 'EdgeContact_2.5mm_Round'이(가) 라이브러리 'SC4'의 사본과 일치하지 않습니다
    Local override; warning
    @(5.0000 mm, 27.5000 mm): 풋프린트 DRIVE-

** Found 0 unconnected pads **

** Found 0 Footprint errors **

** Ignored checks **
    - Footprint has no courtyard defined
    - Track endpoint not centered on via
    - Tuning profile track geometries
    - Footprint doesn't match symbol's footprint filters
    - Footprint component type doesn't match footprint pads

** End of Report **

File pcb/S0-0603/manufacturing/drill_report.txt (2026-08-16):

Drill report for S0-0603.kicad_pcb
Created on 2026-08-16T16:14:09

Copper Layer Stackup:
    =============================================================
    L1 :  F.Cu                      front
    L2 :  B.Cu                      back

Drill file 'S0-0603.drl' contains
    plated through holes:
    =============================================================

    Total plated holes count 0

Not plated through holes are merged with plated holes
    unplated through holes:
    =============================================================
    T1  3.200mm  0.1260"  (4 holes))

    Total unplated holes count 4

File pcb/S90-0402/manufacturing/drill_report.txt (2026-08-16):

Drill report for S90-0402.kicad_pcb
Created on 2026-08-16T16:13:59

Copper Layer Stackup:
    =============================================================
    L1 :  F.Cu                      front
    L2 :  B.Cu                      back

Drill file 'S90-0402.drl' contains
    plated through holes:
    =============================================================

    Total plated holes count 0

Not plated through holes are merged with plated holes
    unplated through holes:
    =============================================================
    T1  3.200mm  0.1260"  (4 holes))

    Total unplated holes count 4

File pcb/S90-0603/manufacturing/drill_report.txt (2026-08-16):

Drill report for S90-0603.kicad_pcb
Created on 2026-08-16T16:14:02

Copper Layer Stackup:
    =============================================================
    L1 :  F.Cu                      front
    L2 :  B.Cu                      back

Drill file 'S90-0603.drl' contains
    plated through holes:
    =============================================================

    Total plated holes count 0

Not plated through holes are merged with plated holes
    unplated through holes:
    =============================================================
    T1  3.200mm  0.1260"  (4 holes))

    Total unplated holes count 4

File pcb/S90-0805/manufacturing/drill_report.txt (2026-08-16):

Drill report for S90-0805.kicad_pcb
Created on 2026-08-16T16:14:04

Copper Layer Stackup:
    =============================================================
    L1 :  F.Cu                      front
    L2 :  B.Cu                      back

Drill file 'S90-0805.drl' contains
    plated through holes:
    =============================================================

    Total plated holes count 0

Not plated through holes are merged with plated holes
    unplated through holes:
    =============================================================
    T1  3.200mm  0.1260"  (4 holes))

    Total unplated holes count 4

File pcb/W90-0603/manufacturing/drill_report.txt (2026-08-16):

Drill report for W90-0603.kicad_pcb
Created on 2026-08-16T16:14:07

Copper Layer Stackup:
    =============================================================
    L1 :  F.Cu                      front
    L2 :  B.Cu                      back

Drill file 'W90-0603.drl' contains
    plated through holes:
    =============================================================

    Total plated holes count 0

Not plated through holes are merged with plated holes
    unplated through holes:
    =============================================================
    T1  3.200mm  0.1260"  (4 holes))

    Total unplated holes count 4

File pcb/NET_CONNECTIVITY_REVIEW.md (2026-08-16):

# Net connectivity review — v0.3.1

## Decision under review

`design/PCB_CAD_ASSUMPTIONS.md` item 4 documents that DRIVE+/SENSE+ share
one KiCad net (`DRIVE_SENSE_PLUS`) and DRIVE-/SENSE- share another
(`DRIVE_SENSE_MINUS`), instead of 4 distinct nets tied together with
KiCad's "net tie" footprint feature. That decision was made before KiCad
was available in this environment, as a syntax-risk-averse choice.

**This review's job**: now that real KiCad is available, confirm whether
that representation is electrically valid, and per the task brief, *keep
it if so* rather than introducing a net-tie "merely for conceptual
elegance."

## What real KiCad DRC found

Running the merged-net representation through actual `kicad-cli pcb drc`
surfaced a real bug unrelated to the net-merging choice itself: the
original routing code used the wrong rotation-sign convention for 90-degree
footprints, so the `+`/`-` labeled traces landed on the wrong physical
pads. This produced genuine `shorting_items` and `unconnected_items`
errors. That bug has been fixed (see `pcb/generate_pcb.py`,
`mlcc_pad_positions()`, and `design/PCB_CAD_ASSUMPTIONS.md` item on
rotation) and is a separate, now-resolved issue from the net-model question
below.

With that routing bug fixed, DRC on all 5 boards, `--severity-all`:

| variant | errors | warnings | unconnected | shorting_items |
|---|---|---|---|---|
| S90-0402 | 0 | 5 (lib_footprint_mismatch) | 0 | 0 |
| S90-0603 | 0 | 5 (lib_footprint_mismatch) | 0 | 0 |
| S90-0805 | 0 | 5 (lib_footprint_mismatch) | 0 | 0 |
| W90-0603 | 0 | 5 (lib_footprint_mismatch) | 0 | 0 |
| S0-0603  | 0 | 5 (lib_footprint_mismatch) | 0 | 0 |

**Zero `shorting_items` violations on any board.** This is the direct test
of whether the merged-net representation is electrically sound in KiCad's
own model: if DRIVE+ and SENSE+ being the same net were somehow still
producing an unwanted connection to something else, or if the DRIVE+/
DRIVE- (opposite terminal) nets were touching anywhere they shouldn't,
DRC's shorting-item and clearance checks would have caught it — the same
class of check that caught the real routing bug above. It didn't, on any
of the 5 boards, across both routing geometries in this design (the direct
3-segment route used for `+`-group traces, the overshoot detour used for
`-`-group traces on 90-degree boards, and the pad-1-bypass detour used on
the 0-degree board).

## Conclusion

**Keep the existing representation.** DRIVE+/SENSE+ sharing
`DRIVE_SENSE_PLUS`, and DRIVE-/SENSE- sharing `DRIVE_SENSE_MINUS`, is
electrically valid in KiCad — confirmed by DRC, not merely asserted by
the earlier written rationale. No net-tie footprint was introduced.

## Final net structure

| KiCad net | member pads | physical meaning |
|---|---|---|
| `DRIVE_SENSE_PLUS` (net 1) | edge pad `DRIVE+`, edge pad `SENSE+`, MLCC pad "1" (+ terminal) | the MLCC's + terminal and both of its external takeoff points (current-carrying drive path and low-current sense path) |
| `DRIVE_SENSE_MINUS` (net 2) | edge pad `DRIVE-`, edge pad `SENSE-`, MLCC pad "2" (- terminal) | the MLCC's - terminal and both of its external takeoff points |

This is a 2-net board. The 4-wire/Kelvin *function* (drive current and
sense current using physically separate copper paths, so DRIVE's trace
resistance doesn't corrupt what SENSE reads) is implemented at the
**routing level** — 4 physically distinct, non-touching traces, each
individually reaching the MLCC pad — not at the netlist level. The netlist
correctly reflects that DRIVE+ and SENSE+ are the same electrical node.

## What would change if a human later wants true 4-net modeling

Nothing about the copper geometry would need to change — only the net
declarations and a `net_tie_pad_groups` attribute on the MLCC footprint
would need to be added, splitting `DRIVE_SENSE_PLUS` into `DRIVE+` and
`SENSE+` (and similarly for the minus side) while marking them as an
intentionally-tied group at the MLCC pad. This is recorded as a possible
future refinement, not a defect in the current design.

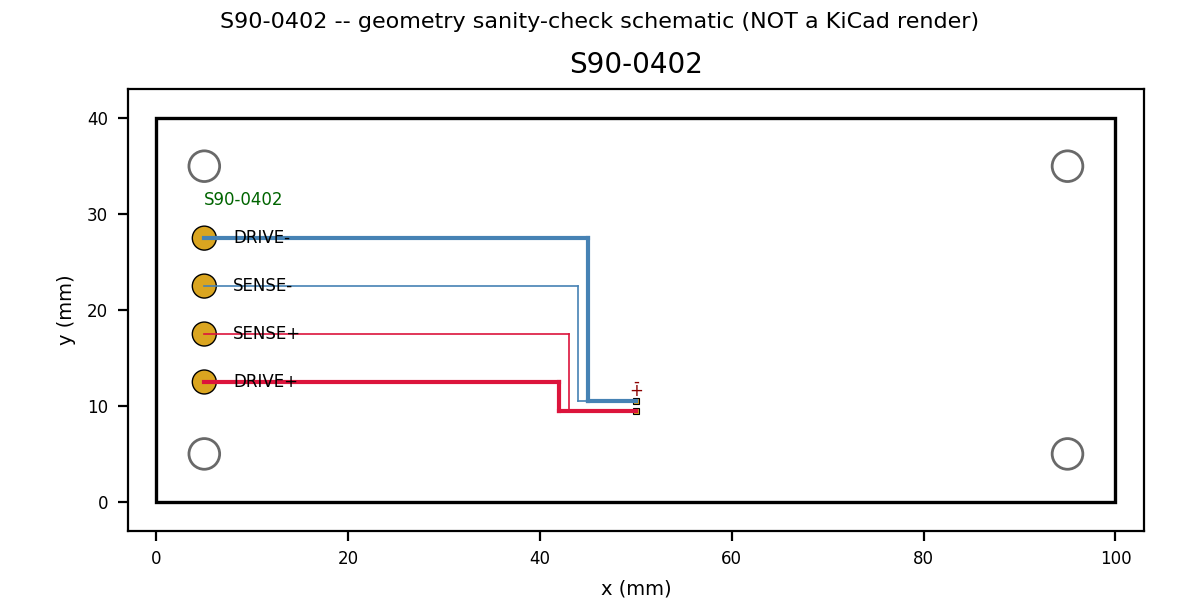
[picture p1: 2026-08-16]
pcb/S90-0402/renders/S90-0402_layout_schematic_NOT_A_KICAD_RENDER.png

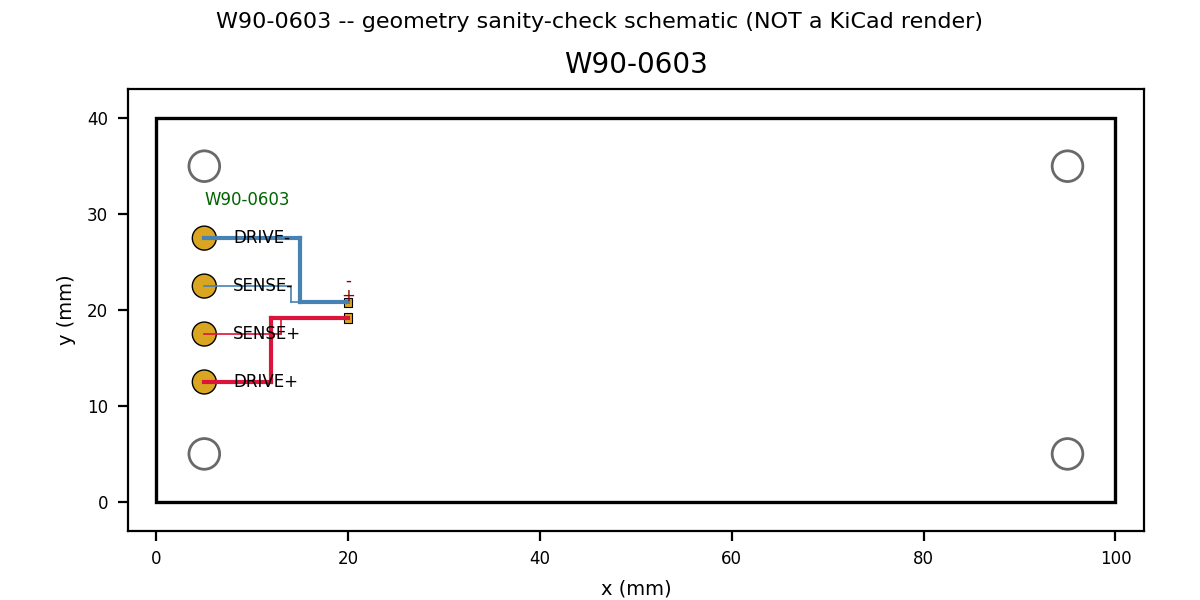
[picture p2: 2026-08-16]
pcb/W90-0603/renders/W90-0603_layout_schematic_NOT_A_KICAD_RENDER.png

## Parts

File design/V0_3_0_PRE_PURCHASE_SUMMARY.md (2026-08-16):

# v0.3.0 pre-purchase summary (A-E)

This is the top-level index for the complete pre-purchase design package.
It does not introduce new content — it ties together v0.3.0-A through -E and
tells a reader where to look for detail. The numerical model
(`README.md`, `model.py`, `source.py`, `plate.py`, `coupling.py`,
`response.py`) and the v0.2.0 simulation results (`out/`) are unchanged
throughout this entire design phase.

## The chain

| stage | what it produced | files |
|---|---|---|
| v0.2.0 | PCB geometry decision (100x40x1.0 mm) via simulation + robustness sweep | `out/final_pcb_recommendation.txt`, `out/pcb_candidate_comparison.csv` |
| v0.3.0-A | 3 experimental roles: S90 (strong), W90 (position-control), S0 (orientation-control) | `pcb_variants.md`, `PRE_PURCHASE_DESIGN.md` |
| v0.3.0-C | 5 fabrication designs (S90 split into 0402/0603/0805) + layout/ordering spec | `PCB_FABRICATION_SPEC.md`, `pcb_variants.csv`, `pcb_coordinates.csv`, `jlcpcb_order_settings.csv`, `pcb_quantity_plan.csv` |
| v0.3.0-D | Electrical drive/measurement protocol (Kelvin sensing, mic geometry, frequency-sweep protocol, data schema) | `ELECTRICAL_MEASUREMENT_SETUP.md`, `equipment_requirements.csv`, `measurement_geometry.csv`, `run_protocol.md`, `data_schema.csv` |
| v0.3.0-E | Final board population, unique specimens, complete non-factorial experiment matrix, go/no-go gate | `board_population_plan.csv`, `specimen_registry.csv`, `final_experiment_matrix.csv`, `experiment_phases.md`, `go_no_go_criteria.md` |

`excitation_plan.csv` was written in v0.3.0-D and superseded in place in
v0.3.0-D itself (Stage 1/Stage 2 protocol); `pcb_quantity_plan.csv` (v0.3.0-C,
generic per-footprint counts) is now superseded in practice by
`board_population_plan.csv` (v0.3.0-E, exact per-role counts) — both are
kept for their original purpose (ordering-form quantity vs. capacitor
population), but the authoritative "what capacitor goes on which board"
answer is `board_population_plan.csv` / `specimen_registry.csv`.

## Final board population (35 boards, 35 unique specimens)

| variant | boards | roles (qty) |
|---|---|---|
| S90-0603 | 15 | R(3), C1(2), C2(2), V1(2), V2(2), V3(2), N1(2) |
| S90-0402 | 5 | P1(3), spare(2) |
| S90-0805 | 5 | P2(3), D1(2) |
| W90-0603 | 5 | R(3), spare(2) |
| S0-0603 | 5 | R(3), spare(2) |

Reference part: **R = 0603ZD105KAT2A** (X5R, 1 uF, 10 V, 0603) — the only
specific commercial part number in this entire design. Every other role
(C1, C2, V1, V2, V3, N1, P1, P2, D1) is specified only by dielectric /
capacitance / rated voltage / package and marked `TBD` for part number —
**no other commercial MLCC part numbers are chosen at this stage.**

Every specimen has a unique ID (`specimen_id` in `specimen_registry.csv`,
e.g. `S90-0603-R-01`). No PCB is ever assumed to be desoldered and reused
with a different MLCC.

## Required vs. optional runs

From `final_experiment_matrix.csv` (308 rows total):

- **296 rows are required**: Phase 0 (2), Phase 1 (54), Phase 2 (54),
  Phase 3 (42), Phase 4 (54), Phase 5 (30), Phase 6 baseline (12), Phase 7
  (24), Phase 8 (24).
- **12 rows are optional**: Phase 6's 0.50 V_peak C0G sensitivity check,
  run only if the baseline (0.10 V_peak) response is below reliable
  acoustic SNR. Its result must not be treated as a direct quantitative
  comparison against the X5R parts.
- Of the required rows, **212 require a new physical measurement**; the
  remaining **84** are the same physical condition already captured
  elsewhere (66 reused from Phase 1, 18 reused from Phase 2) and are
  referenced rather than re-measured, per the non-factorial design.

## Measurements that depend on fr1/fr2/fr3

**Every row except Phase 0** depends on fr1, fr2, and/or fr3 — Phase 0 is
what defines them; every later phase uses the standard six-frequency set
(`fr1, fr2, fr3, fr1/2, fr2/2, fr3/2`) or the `fr_star`/`fr_star/2` pair
derived from them. This is by design: the entire experiment matrix is built
on top of a single resonance-identification run (`experiment_phases.md`
Phase 0), not on the v0.2.0 simulation's predicted 1090/1541/2293 Hz values,
which are guides only (`README.md` section 6; `out/final_pcb_recommendation.txt`).

**No numerical value has been substituted for fr1, fr2, or fr3 anywhere in
this design.** Every file that references them (`final_experiment_matrix.csv`
`freq_label`/`freq_spec` columns, `experiment_phases.md`,
`go_no_go_criteria.md`) uses the symbolic labels and an explicit "not yet
available" placeholder.

## Quantities that cannot be filled until the physical PCB is tested

- The literal Hz values of fr1, fr2, fr3 (and therefore fr1/2, fr2/2, fr3/2,
  fr_star, and fr_star/2) — only exist after Phase 0 is physically run.
- Every measured outcome field for every row of every phase: actual
  measured `V_DUT`, `I_peak` (measured, if the commissioning shunt is used),
  acoustic amplitude at `f`, acoustic amplitude at `2f` — see
  `data_schema.csv` for the exact fields these populate. `final_experiment_matrix.csv`
  is a plan of conditions to run, not a results table; none of its rows have
  measured data yet.
- Whether the go/no-go gate passes (`go_no_go_criteria.md`) — and therefore
  whether Phases 2-8 proceed at all.
- Which specific capacitors satisfy the `TBD` roles (C1, C2, V1, V2, V3, N1,
  P1, P2, D1) — those are chosen at order time from the stated electrical
  specs, not fixed here.

## What did not change in this phase

- No modification to the numerical model or to v0.2.0 simulation results.
- No FEM, acoustic radiation model, solder-joint model, or higher-fidelity
  MLCC physics was added at any point across v0.3.0-A through -E.
- No commercial MLCC part number was invented for any candidate role.
- No numerical resonance frequency was invented in place of fr1/fr2/fr3.

## Reading order for someone new to this package

1. `README.md` (model), `out/final_pcb_recommendation.txt` (why this PCB).
2. `pcb_variants.md`, `PRE_PURCHASE_DESIGN.md` (experimental roles).
3. `PCB_FABRICATION_SPEC.md` (what to actually fabricate).
4. `ELECTRICAL_MEASUREMENT_SETUP.md`, `run_protocol.md` (how to drive and
   measure it).
5. `board_population_plan.csv`, `specimen_registry.csv`,
   `experiment_phases.md`, `go_no_go_criteria.md`, `final_experiment_matrix.csv`
   (what to actually run, in what order, and when to stop).

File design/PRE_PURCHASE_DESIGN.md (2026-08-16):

# Pre-purchase experimental design — v0.3.0

This is the final design package to review before ordering PCBs and MLCCs
for the singing-capacitor experiment. It carries forward the v0.2.0
simulation result as a fixed design basis and does not change the physics
model — see `README.md` for the model itself and `out/` for the v0.2.0
sweep results this design is built on.

## 1. Design basis (from v0.2.0)

Source: `out/final_pcb_recommendation.txt`, `out/pcb_candidate_comparison.csv`.

| parameter | value |
|---|---|
| PCB outline | 100 mm x 40 mm |
| PCB thickness | 1.0 mm |
| strong-response MLCC position | x/a=0.50, y/b=0.25 (x=50 mm, y=10 mm) |
| strong-response orientation | 90 deg |
| weak-control MLCC position | x/a=0.20, y/b=0.50 (x=20 mm, y=20 mm) |
| predicted resonances | 1090, 1541, 2293 Hz |
| predicted resonance spacing | 451, 752 Hz |
| predicted strong/control response ratio | 4.9x |
| predicted 0deg/90deg orientation ratio | 1.8x (90 deg stronger) |

These predictions come from an isotropic simply-supported thin-plate model
with a lumped MLCC source (README.md section 1). They are guides for board
geometry and MLCC placement, not exact experimental predictions — real
resonances will shift once the board is manufactured and mounted (README.md
section 6, "Known limitations").

**This design step does not add fidelity to that model.** No FEM, acoustic
radiation model, solder-joint model, or detailed MLCC electromechanical
model is introduced here. The task at this stage is translating an already-
decided PCB geometry and placement/orientation strategy into an orderable,
testable design.

## 2. What to order: three PCB variants

| variant | MLCC center (x, y) | orientation | purpose |
|---|---|---|---|
| **S90** | 50 mm, 10 mm | 90 deg | primary strong-response board; all capacitor candidates tested here |
| **W90** | 20 mm, 20 mm | 90 deg | position-control board; reference MLCC only |
| **S0**  | 50 mm, 10 mm | 0 deg  | orientation-control board; reference MLCC only |

All three share the same 100x40 mm outline, 1.0 mm thickness spec, mounting
scheme, electrical connection strategy, and test-pad strategy — only MLCC
placement/orientation differs. Full rationale and the shared specification
are in `pcb_variants.md`; machine-readable coordinates are in
`pcb_coordinates.csv`.

Order enough copies of each variant to allow for at least one spare per
variant (manufacturing tolerance and handling damage are the main risk at
this thickness) — decide the exact panel/quantity with the PCB vendor once
this design is reviewed; that is a purchasing decision, not a modeling one.

## 3. Experimental principles

These apply to every board and every run, and are restated in full (with
the reasoning behind each) in `pcb_variants.md`:

1. External wires attach near the PCB edge, not near the vibrating MLCC.
2. DUT voltage is measured directly across the capacitor, not read off the
   function generator, since the generator setting is not necessarily the
   actual MLCC voltage.
3. Account for the capacitive drive current `I_peak = 2*pi*f*C*V_peak` when
   choosing drive levels, especially near the top of the swept range.
4. Sweep order: broad experimental sweep first (to find the actual PCB
   resonances), then dense sweeps around the measured resonances and around
   half those frequencies (to test for 2f electrostrictive excitation).
5. Use one reference MLCC on S90, W90, and S0 to validate the simulated
   position and orientation effects before testing anything else.
6. Test all other capacitor-property candidates primarily on S90.
7. No commercial MLCC part numbers are chosen yet — candidates are tracked
   as placeholders (`TBD-1`, `TBD-2`, ...) until the reference measurements
   validate the board design.

## 4. Sweep and data-logging plan

- `excitation_plan.csv` — the frequency-sweep plan: phase 1 is a broad
  200-3000 Hz sweep on all three boards to locate actual resonances; phase 2
  is a dense sweep on S90 around each predicted resonance and each predicted
  half-resonance (provisional, to be recentered on the measured values);
  phase 3 repeats the dense sweep on W90 and S0 once phase 1 gives the
  measured resonance to center on.
- `experiment_matrix_template.csv` — one row per planned (board, capacitor,
  frequency-band) combination, with the measurement columns left blank to
  fill in during testing (drive voltage, measured DUT voltage, predicted
  `I_peak`, and the measured vibration response). Pre-populated with the
  reference MLCC across all three boards and three candidate placeholders
  on S90.

## 5. Files in this directory

| file | contents |
|---|---|
| `pcb_variants.md` | full per-variant rationale, shared spec, and the experimental principles above |
| `pcb_coordinates.csv` | machine-readable MLCC position/orientation per variant |
| `excitation_plan.csv` | broad + dense frequency-sweep plan per board |
| `experiment_matrix_template.csv` | blank run log to fill in during testing |
| `PRE_PURCHASE_DESIGN.md` | this file |

## 6. Open decisions before placing the order

These are purchasing/logistics decisions, not modeling ones, and are left
for explicit sign-off rather than assumed:

- exact PCB vendor, stack-up/copper spec, and quantity per variant,
- connector/pad footprint for the drive leads and test pads,
- which reference MLCC to use for the position/orientation validation
  (its capacitance should be roughly representative of the eventual
  candidates, so the `I_peak` estimate for phase-1/2 testing is realistic).

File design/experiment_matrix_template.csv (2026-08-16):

run_id | board | mlcc_x_mm | mlcc_y_mm | orientation_deg | capacitor_role | capacitor_id | sweep_type | freq_start_hz | freq_end_hz | based_on_predicted_hz | function_gen_Vpp | function_gen_freq_hz | DUT_Vpp_measured | DUT_Vpeak_measured | C_nominal_nF | I_peak_predicted_mA | vibration_metric | vibration_value | vibration_units | notes
R001 | S90 | 50 | 10 | 90 | reference | REF | broad | 200 | 3000 | n/a
R002 | S90 | 50 | 10 | 90 | reference | REF | dense-f | 927 | 1254 | 1090
R003 | S90 | 50 | 10 | 90 | reference | REF | dense-f | 1310 | 1772 | 1541
R004 | S90 | 50 | 10 | 90 | reference | REF | dense-f | 1949 | 2637 | 2293
R005 | S90 | 50 | 10 | 90 | reference | REF | dense-2f | 463 | 627 | 545
R006 | S90 | 50 | 10 | 90 | reference | REF | dense-2f | 655 | 886 | 770.6
R007 | S90 | 50 | 10 | 90 | reference | REF | dense-2f | 975 | 1319 | 1146.6
R008 | W90 | 20 | 20 | 90 | reference | REF | broad | 200 | 3000 | n/a
R009 | W90 | 20 | 20 | 90 | reference | REF | dense-f | 927 | 1254 | 1090
R010 | W90 | 20 | 20 | 90 | reference | REF | dense-f | 1310 | 1772 | 1541
R011 | W90 | 20 | 20 | 90 | reference | REF | dense-f | 1949 | 2637 | 2293
R012 | W90 | 20 | 20 | 90 | reference | REF | dense-2f | 463 | 627 | 545
R013 | W90 | 20 | 20 | 90 | reference | REF | dense-2f | 655 | 886 | 770.6
R014 | W90 | 20 | 20 | 90 | reference | REF | dense-2f | 975 | 1319 | 1146.6
R015 | S0 | 50 | 10 | 0 | reference | REF | broad | 200 | 3000 | n/a
R016 | S0 | 50 | 10 | 0 | reference | REF | dense-f | 927 | 1254 | 1090
R017 | S0 | 50 | 10 | 0 | reference | REF | dense-f | 1310 | 1772 | 1541
R018 | S0 | 50 | 10 | 0 | reference | REF | dense-f | 1949 | 2637 | 2293
R019 | S0 | 50 | 10 | 0 | reference | REF | dense-2f | 463 | 627 | 545
R020 | S0 | 50 | 10 | 0 | reference | REF | dense-2f | 655 | 886 | 770.6
R021 | S0 | 50 | 10 | 0 | reference | REF | dense-2f | 975 | 1319 | 1146.6
R022 | S90 | 50 | 10 | 90 | candidate | TBD-1 | broad | 200 | 3000 | n/a
R023 | S90 | 50 | 10 | 90 | candidate | TBD-1 | dense-f | 927 | 1254 | 1090
R024 | S90 | 50 | 10 | 90 | candidate | TBD-1 | dense-f | 1310 | 1772 | 1541
R025 | S90 | 50 | 10 | 90 | candidate | TBD-1 | dense-f | 1949 | 2637 | 2293
R026 | S90 | 50 | 10 | 90 | candidate | TBD-1 | dense-2f | 463 | 627 | 545
R027 | S90 | 50 | 10 | 90 | candidate | TBD-1 | dense-2f | 655 | 886 | 770.6
R028 | S90 | 50 | 10 | 90 | candidate | TBD-1 | dense-2f | 975 | 1319 | 1146.6
R029 | S90 | 50 | 10 | 90 | candidate | TBD-2 | broad | 200 | 3000 | n/a
R030 | S90 | 50 | 10 | 90 | candidate | TBD-2 | dense-f | 927 | 1254 | 1090
R031 | S90 | 50 | 10 | 90 | candidate | TBD-2 | dense-f | 1310 | 1772 | 1541
R032 | S90 | 50 | 10 | 90 | candidate | TBD-2 | dense-f | 1949 | 2637 | 2293
R033 | S90 | 50 | 10 | 90 | candidate | TBD-2 | dense-2f | 463 | 627 | 545
R034 | S90 | 50 | 10 | 90 | candidate | TBD-2 | dense-2f | 655 | 886 | 770.6
R035 | S90 | 50 | 10 | 90 | candidate | TBD-2 | dense-2f | 975 | 1319 | 1146.6
R036 | S90 | 50 | 10 | 90 | candidate | TBD-3 | broad | 200 | 3000 | n/a
R037 | S90 | 50 | 10 | 90 | candidate | TBD-3 | dense-f | 927 | 1254 | 1090
R038 | S90 | 50 | 10 | 90 | candidate | TBD-3 | dense-f | 1310 | 1772 | 1541
R039 | S90 | 50 | 10 | 90 | candidate | TBD-3 | dense-f | 1949 | 2637 | 2293
R040 | S90 | 50 | 10 | 90 | candidate | TBD-3 | dense-2f | 463 | 627 | 545
R041 | S90 | 50 | 10 | 90 | candidate | TBD-3 | dense-2f | 655 | 886 | 770.6
R042 | S90 | 50 | 10 | 90 | candidate | TBD-3 | dense-2f | 975 | 1319 | 1146.6

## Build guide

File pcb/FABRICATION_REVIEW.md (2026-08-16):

# PCB fabrication review — v0.3.1

## Environment status

**KiCad 10.0.5 is installed** (`/Applications/KiCad/KiCad.app`,
`kicad-cli` confirmed working) and was used as the source of truth for
every check below: real parse/load, real DRC, real Gerber/drill export
from the KiCad engine (not a separate custom implementation), and real
`kicad-cli pcb render` 3D output. This supersedes the earlier v0.3.1 pass,
which was produced before KiCad was available and explicitly marked every
board `READY_FOR_JLCPCB: NO` for that reason.

Two real bugs were found and fixed while validating against actual KiCad
(not assumptions) — full detail in `design/PCB_CAD_ASSUMPTIONS.md` and
`pcb/NET_CONNECTIVITY_REVIEW.md`:

1. **Rotation-convention bug**: the original routing code assumed a
   counter-clockwise pad-rotation convention; KiCad's actual convention is
   clockwise in its stored (x, y-down) frame. This caused the DRIVE+/
   SENSE+ traces to land on the physical `-` pad and vice versa on every
   90-degree board — a real short, caught by `kicad-cli pcb drc`
   (`shorting_items`), not by the custom validator (which checked against
   its own, equally wrong, assumption). Fixed in `mlcc_pad_positions()`.
2. **Routing-topology bug**: after fixing (1), a *different* real crossing
   appeared — proven analytically to have no solution using simple
   monotonic-lane ordering, because the '+' and '-' groups' transit paths
   mutually cross through each other's target point (worst on W90-0603,
   where both directions conflict simultaneously). Fixed by routing the
   '-' group (SENSE-, DRIVE-) via a detour that overshoots past the MLCC's
   x-position, using board area the '+' group never touches.

No PCB coordinates, dimensions, or package assignments from v0.3.0 were
changed to fix either bug — both were pure routing/implementation issues.

## Per-board record — all verified against real KiCad

All 5 variants share: 100 x 40 mm outline, FR-4, 2 layers, 1.0 mm nominal
thickness, 1 oz copper, ENIG, no copper pours, no B.Cu routing, no vias, no
onboard connectors, 4x NPTH 3.2 mm mounting holes at (5,5) (95,5) (5,35)
(95,35) mm.

### S90-0402

| item | value |
|---|---|
| MLCC center / orientation | (50, 10) mm / 90 deg |
| Footprint | 0402 (pad 0.6x0.6mm, pitch 1.0mm), standard KiCad 3D model attached |
| KiCad parse | **PASS** |
| Custom geometry validation | **PASS** (13/13) |
| KiCad DRC errors | **0** |
| KiCad DRC warnings | 5, all `lib_footprint_mismatch` (intentional/expected — see below) |
| Gerber export | **PASS** (F.Cu, F.Mask, F.Silkscreen, Edge.Cuts + job file) |
| Drill verification | **PASS** (4 NPTH @ exact coords, 0 plated holes) |
| Visual Gerber inspection | **PASS** (per-layer + composite renders, programmatic bounds/location checks) |
| 3D visual inspection | **PASS** (top/bottom/perspective renders) |
| Gerber ZIP | `manufacturing/S90-0402_JLCPCB_Gerber.zip` |
| **READY_FOR_JLCPCB** | **YES** |

### S90-0603

| item | value |
|---|---|
| MLCC center / orientation | (50, 10) mm / 90 deg |
| Footprint | 0603 (pad 0.9x1.0mm, pitch 1.6mm), standard KiCad 3D model attached |
| KiCad parse | **PASS** |
| Custom geometry validation | **PASS** (13/13) |
| KiCad DRC errors | **0** |
| KiCad DRC warnings | 5, all `lib_footprint_mismatch` (intentional/expected) |
| Gerber export | **PASS** |
| Drill verification | **PASS** (4 NPTH @ exact coords, 0 plated holes) |
| Visual Gerber inspection | **PASS** |
| 3D visual inspection | **PASS** |
| Gerber ZIP | `manufacturing/S90-0603_JLCPCB_Gerber.zip` |
| **READY_FOR_JLCPCB** | **YES** |

### S90-0805

| item | value |
|---|---|
| MLCC center / orientation | (50, 10) mm / 90 deg |
| Footprint | 0805 (pad 1.2x1.45mm, pitch 1.9mm), standard KiCad 3D model attached |
| KiCad parse | **PASS** |
| Custom geometry validation | **PASS** (13/13) |
| KiCad DRC errors | **0** |
| KiCad DRC warnings | 5, all `lib_footprint_mismatch` (intentional/expected) |
| Gerber export | **PASS** |
| Drill verification | **PASS** (4 NPTH @ exact coords, 0 plated holes) |
| Visual Gerber inspection | **PASS** |
| 3D visual inspection | **PASS** |
| Gerber ZIP | `manufacturing/S90-0805_JLCPCB_Gerber.zip` |
| **READY_FOR_JLCPCB** | **YES** |

### W90-0603

| item | value |
|---|---|
| MLCC center / orientation | (20, 20) mm / 90 deg |
| Footprint | 0603, standard KiCad 3D model attached |
| Routing note | this is the geometrically hardest case (targets straddle both edge-pad groups — see `NET_CONNECTIVITY_REVIEW.md`); verified crossing-free by both the custom validator's segment-intersection check and real DRC |
| KiCad parse | **PASS** |
| Custom geometry validation | **PASS** (13/13) |
| KiCad DRC errors | **0** |
| KiCad DRC warnings | 5, all `lib_footprint_mismatch` (intentional/expected) |
| Gerber export | **PASS** |
| Drill verification | **PASS** (4 NPTH @ exact coords, 0 plated holes) |
| Visual Gerber inspection | **PASS** |
| 3D visual inspection | **PASS** |
| Gerber ZIP | `manufacturing/W90-0603_JLCPCB_Gerber.zip` |
| **READY_FOR_JLCPCB** | **YES** |

### S0-0603

| item | value |
|---|---|
| MLCC center / orientation | (50, 10) mm / 0 deg |
| Footprint | 0603, standard KiCad 3D model attached |
| Routing note | only board using the pad-1-bypass detour (orientation=0 case); clearance margin was tightened after real DRC found the original 0.3mm-from-centerline margin left only 0.05mm actual clearance |
| KiCad parse | **PASS** |
| Custom geometry validation | **PASS** (13/13) |
| KiCad DRC errors | **0** |
| KiCad DRC warnings | 5, all `lib_footprint_mismatch` (intentional/expected) |
| Gerber export | **PASS** |
| Drill verification | **PASS** (4 NPTH @ exact coords, 0 plated holes) |
| Visual Gerber inspection | **PASS** |
| 3D visual inspection | **PASS** |
| Gerber ZIP | `manufacturing/S0-0603_JLCPCB_Gerber.zip` |
| **READY_FOR_JLCPCB** | **YES** |

## DRC warning classification

Every board reports exactly 5 `lib_footprint_mismatch` warnings (one for
the MLCC footprint, four for the edge-contact footprints), after adding a
per-board `fp-lib-table`/`.kicad_pro` resolved the *worse* "library not
found" warning that appeared before those existed. This is **intentional
and expected**: the warning fires because the embedded footprint instance
(which carries net assignments, position, and a UUID) differs from the
bare library master copy (which has none of that, by definition — a
library part isn't wired to anything). This does not affect fabrication:
the actual copper/pad/silkscreen geometry that gets plotted into the
Gerbers comes entirely from the embedded instance, not the library master.
The mounting-hole footprint (`NPTH_3.2mm`) has no such mismatch, since it
carries no net data to differ on.

## Gerber contents (all 5 ZIPs)

Exactly the 4 requested layers plus KiCad's standard Gerber job file
(`*-job.gbrjob`, a small JSON manifest describing the layer stack — kept
since JLCPCB and most fabs use it to auto-configure the order, not an
"unnecessary empty layer"): `F.Cu`, `F.Mask`, `F.Silkscreen`,
`Edge.Cuts`, plus the Excellon drill file. No other layers were exported —
B.Cu, B.Mask, B.Silkscreen, and paste layers were confirmed empty/unused
by design and correctly excluded.

## Visual verification artifacts

Per variant, under `<variant>/renders/`:
- `<variant>_top.png`, `<variant>_bottom.png`, `<variant>_perspective.png` —
  real `kicad-cli pcb render` 3D output (high quality, floor/shadows on).
  Bottom view confirms bare substrate (no bottom copper); top/perspective
  confirm MLCC position, orientation, and package size visually, with a
  standard KiCad 3D body attached per package (0402/0603/0805) so the part
  is actually visible, not just its footprint outline.

Per variant, under `<variant>/manufacturing/gerber_verification/`:
- Per-layer PNGs (top copper, solder mask, silkscreen, edge cuts) plus a
  composite, rendered from the **actual exported Gerber files** via
  `kicad-cli pcb export svg` (the same plot engine that generated the
  Gerbers) converted to PNG — not re-renders of the source PCB.

`pcb/PCB_5_VARIANT_COMPARISON.png` — all 5 top-view renders at identical
camera/zoom settings, stacked and labeled for direct scale comparison.

## Files in this directory

```
pcb/
├── generate_pcb.py                  generator (source of truth for all 5 boards)
├── validate_pcb.py                  custom geometry/connectivity checker (pre-check, not a DRC substitute)
├── verify_gerbers.py                Gerber-file rendering + programmatic verification (Step 6)
├── render_3d.py                     kicad-cli pcb render driver (Step 7)
├── make_comparison.py               builds PCB_5_VARIANT_COMPARISON.png
├── generate_schematics.py           earlier (pre-KiCad) non-KiCad sanity diagrams, superseded by real renders
├── PCB_5_VARIANT_COMPARISON.png
├── FABRICATION_REVIEW.md            this file
├── NET_CONNECTIVITY_REVIEW.md       Step 3 net-model review
├── SC4.pretty/                      local footprint library (.kicad_mod files)
└── <variant>/
    ├── <variant>.kicad_pcb          board source, real-KiCad validated
    ├── <variant>.kicad_pro          minimal project file (enables fp-lib-table resolution)
    ├── fp-lib-table                 points the project at ../SC4.pretty
    ├── manufacturing/
    │   ├── validation_report.txt              custom validator output
    │   ├── drc_report.txt                     real kicad-cli DRC report
    │   ├── drill_report.txt                   real kicad-cli drill report
    │   ├── gerbers/                            raw exported Gerber + drill files
    │   ├── gerber_verification/                per-layer + composite PNGs, from the actual Gerbers
    │   ├── gerber_verification_report.txt      programmatic Gerber checks
    │   └── <variant>_JLCPCB_Gerber.zip         fabrication deliverable
    └── renders/
        └── <variant>_top.png, _bottom.png, _perspective.png
```

See `pcb/v0.3.1_FABRICATION_PACKAGE_SUMMARY.md` for the top-level summary
of this entire package.

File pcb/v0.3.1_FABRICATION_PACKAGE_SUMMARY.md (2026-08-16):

# v0.3.1 fabrication package summary

## Result

**All 5 PCB variants are READY_FOR_JLCPCB.** This is the first point in
the v0.3.x series where that claim is actually backed by real KiCad
validation — every earlier "not ready" status was correct at the time
(KiCad wasn't installed), and this pass supersedes it after installing
KiCad 10.0.5 and re-deriving every check against it.

| variant | KiCad parse | custom validation | DRC errors | Gerbers | drill | Gerber visual | 3D visual | READY |
|---|---|---|---|---|---|---|---|---|
| S90-0402 | PASS | PASS | 0 | PASS | PASS | PASS | PASS | **YES** |
| S90-0603 | PASS | PASS | 0 | PASS | PASS | PASS | PASS | **YES** |
| S90-0805 | PASS | PASS | 0 | PASS | PASS | PASS | PASS | **YES** |
| W90-0603 | PASS | PASS | 0 | PASS | PASS | PASS | PASS | **YES** |
| S0-0603  | PASS | PASS | 0 | PASS | PASS | PASS | PASS | **YES** |

Full per-board detail: `pcb/FABRICATION_REVIEW.md`.

## What changed since the last (pre-KiCad) pass

1. **KiCad 10.0.5 installed** (with your explicit go-ahead, after the
   automated `brew install --cask` attempt failed on an interactive-sudo
   requirement — you ran it manually).
2. **Two real bugs found and fixed**, both only discoverable by actually
   running KiCad (the custom validator's self-consistency checks passed
   throughout, since they checked the generator's output against its own
   assumptions):
   - A pad-rotation sign-convention bug that put DRIVE+/SENSE+ copper on
     the physical `-` terminal (and vice versa) on every 90-degree board —
     a real short, per `kicad-cli pcb drc`'s `shorting_items` check.
   - A routing-topology bug (proven to have no monotonic-lane solution,
     worst on W90-0603) fixed with an overshoot-past-the-MLCC detour for
     the `-`-group traces.
3. **Real DRC, Gerbers, drill files, and 3D renders** now exist for all 5
   boards, generated directly from KiCad (`kicad-cli`), not approximated.
4. **Net model reviewed against real DRC** (Step 3): the merged-net
   representation (DRIVE+/SENSE+ share one net, DRIVE-/SENSE- share the
   other) was kept, not replaced with a KiCad net-tie, because DRC
   confirmed zero shorting violations under it — see
   `pcb/NET_CONNECTIVITY_REVIEW.md`.

## What did not change

- No PCB dimensions, MLCC coordinates, mounting-hole coordinates, or
  package assignments were altered. Every fix was to routing
  implementation (trace paths, a clearance margin, a rotation-sign
  convention), never to the v0.3.0 design values themselves.
- No inconsistency was found between this task's stated spec and the
  existing `pcb_variants.csv`/`pcb_coordinates.csv` — nothing needed to be
  reported before proceeding.
- The numerical simulation and experimental design (`design/`, `out/`)
  were not touched.

## Fabrication deliverables

For each variant, `pcb/<variant>/manufacturing/<variant>_JLCPCB_Gerber.zip`
contains exactly: `F.Cu`, `F.Mask`, `F.Silkscreen`, `Edge.Cuts` Gerbers, the
Excellon drill file (4 NPTH holes, 0 plated), and KiCad's standard Gerber
job-file manifest. No unused/empty layers were included.

## Verification chain (how "READY" was earned, not asserted)

1. Real KiCad load/parse (implicit in every command below succeeding).
2. Custom geometry/connectivity validator (`validate_pcb.py`) — 13/13
   checks per board, useful as a fast pre-check but explicitly not a DRC
   substitute.
3. Real `kicad-cli pcb drc`, `--severity-all` — 0 errors, 5 classified
   warnings (benign `lib_footprint_mismatch`) per board.
4. Real `kicad-cli pcb export gerbers` / `export drill` — from the KiCad
   engine, not a custom exporter.
5. Gerber-level verification (`verify_gerbers.py`) — re-rendered the
   *actual exported Gerber files* (not the source PCB) via `kicad-cli pcb
   export svg`, plus direct programmatic parsing of the Gerber/drill text
   for outline bounds, drill centers, copper extent, and MLCC location.
6. Real `kicad-cli pcb render` 3D output (`render_3d.py`) — top, bottom,
   perspective, per board, with a standard KiCad 3D body attached per
   package size (0402/0603/0805 — reused verbatim from KiCad's own
   `Capacitor_SMD.3dshapes` library, footprint pads unchanged) so the part
   is visibly present, not just implied by its pads.
7. `pcb/PCB_5_VARIANT_COMPARISON.png` — all 5 boards, same camera/zoom,
   confirming MLCC position/orientation differences are visually correct
   (W90-0603 offset left, S0-0603 horizontal vs. the others' vertical).

## Reading order

1. `pcb/FABRICATION_REVIEW.md` — full per-board record and file map.
2. `pcb/NET_CONNECTIVITY_REVIEW.md` — the net-model decision and why it
   was kept.
3. `design/PCB_CAD_ASSUMPTIONS.md` — every fabrication parameter that
   wasn't already fixed by v0.3.0, including both bugs found and fixed in
   this pass.
4. `pcb/<variant>/manufacturing/` — DRC report, drill report, raw Gerbers,
   Gerber-verification images/report, and the JLCPCB ZIP, per board.

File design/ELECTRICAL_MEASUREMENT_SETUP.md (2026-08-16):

# Electrical drive and measurement setup — v0.3.0-D

This is the electrical and measurement protocol for the pre-purchase
experimental design. It does not change the numerical model or the v0.2.0
simulation results (`out/`), and it does not change the PCB fabrication
spec (`PCB_FABRICATION_SPEC.md`) — it defines how those boards are driven
and measured once built.

## 1. Drive architecture

```
Function generator (DC-coupled output, Vdc offset + Vac_peak)
    OUT+ ----> DRIVE+ pad ----> MLCC (+ terminal)
    OUT- ----> DRIVE- pad ----> MLCC (- terminal) ----> common ground
                                                          = generator ground
                                                          = oscilloscope reference

Kelvin sense taps at the MLCC pads (see PCB_FABRICATION_SPEC.md section 5):
    MLCC (+ terminal) ----> SENSE+ pad ----> scope CH1
    MLCC (- terminal) ----> SENSE- pad ----> scope CH2

    V_DUT(t) = CH1(t) - CH2(t)     preferred, when 2 channels are captured
    V_DUT(t) ~= CH1(t)             acceptable if only 1 channel is available,
                                    since DRIVE- = ground and SENSE- should
                                    sit within a small tolerance of 0 V;
                                    verify that tolerance at least once per
                                    session by capturing SENSE- alone
```

The direct function-generator drive shown above is the default and baseline
for every run in this design. **No external power amplifier is used unless
the measured DUT voltage waveform shows amplitude collapse, clipping, or
current-limit behavior** (see section 6 for how to recognize that, and
section 8 for the fallback amplifier spec — not a selection or purchase).

## 2. Voltage convention

**All stored AC amplitudes use V_peak, not V_pp and not V_rms.** Record and
report V_peak consistently across every file in this design package.

Initial excitation levels to step through, in order (start at the lowest and
escalate only as the protocol calls for it):

| Vac_peak (V) | Vdc (V) |
|---|---|
| 0.05 | 0 |
| 0.10 | 1 |
| 0.25 | 2 |
| 0.50 | 2.8 |

These are independent lists (any Vac_peak may be paired with any Vdc), not a
fixed 1:1 pairing — subject to the voltage-budget rule below.

**The experimental voltage is the actual measured `V_DUT` (from the SENSE
traces), not the function-generator's displayed setting.** Cable/contact
resistance and the capacitor's own reactive loading mean the two are not
guaranteed to match, especially as frequency and drive current rise.

### Voltage budget (hard rule)

```
|Vdc| + Vac_peak  <=  capacitor rated voltage
```

Check this **before** every run, using the *planned* generator setting (as
a conservative pre-check) and again using the *measured* `V_DUT` once
captured. Do not drive a condition that violates this for the capacitor
under test. Example: the most extreme combination in the table above,
Vdc=2.8 V with Vac_peak=0.50 V, requires |Vdc|+Vac_peak = 3.3 V of rated
voltage headroom — skip that combination for any capacitor rated below
3.3 V.

## 3. Drive current

```
I_peak = 2 * pi * f * C * V_peak
```

Estimate `I_peak` for the capacitor's nominal `C` before every sweep,
across the frequency and voltage range about to be run, and compare against
the guidance in section 5. Worked example at `V_peak = 0.50 V` (the highest
initial level) for illustrative generic capacitance values (not specific
part numbers):

| C | I_peak @ 200 Hz | I_peak @ 3000 Hz | I_peak @ 20000 Hz |
|---|---|---|---|
| 1 nF | 0.001 mA | 0.009 mA | 0.063 mA |
| 10 nF | 0.006 mA | 0.094 mA | 0.628 mA |
| 100 nF | 0.063 mA | 0.942 mA | 6.283 mA |
| 1 uF | 0.628 mA | 9.425 mA | 62.832 mA |
| 10 uF | 6.283 mA | 94.248 mA | 628.319 mA |

A 1 uF-class capacitor crosses the 25 mA Stage-1 guideline (section 5)
around ~8 kHz at 0.50 V_peak — well inside the 3-20 kHz high band. This is
exactly the kind of condition the direct-drive-by-default policy is meant
to catch: if the measured `V_DUT` waveform collapses or clips near there,
that is the trigger to consider the fallback amplifier, not to keep pushing
the function generator past its comfortable output range.

## 4. Acoustic and vibration measurement

**Primary measurement — calibrated microphone:**

- calibrated measurement microphone, sensitivity/calibration on file,
- positioned 100 mm vertically above PCB center, pointing down at the
  board,
- identical position and fixture for every run and every board variant
  (see `measurement_geometry.csv` — the mic tracks PCB center, not MLCC
  position, so board-to-board comparisons are not confounded by a moving
  microphone).

**Optional validation — LDV:** a laser Doppler vibrometer may be used for
spot validation of the model's mechanical-velocity prediction, independent
of the acoustic path. Not required for any baseline run.

**Not required in the baseline:** an accelerometer is not required. Adding
one later is a possible extension, not part of this design.

## 5. Frequency protocol

### Stage 1 — broad resonance search

| band | range | step |
|---|---|---|
| low | 200-3000 Hz | 25 Hz |
| high | 3000-20000 Hz | 100 Hz |

- Use the lowest available excitation level (0.05 V_peak) by default;
  escalate only if signal-to-noise in the microphone recording is
  insufficient to identify peaks.
- Keep peak current approximately <= 25 mA where practical (check with the
  `I_peak` formula above against the capacitor actually mounted).
- This scan is for **locating resonances only** — it is not a quantitative
  capacitor comparison. Do not draw capacitor-property conclusions from
  Stage-1 amplitudes.

### Stage 2 — dense scan

For every resonance `fr` found in Stage 1, on that same board:

- scan `fr +/- 100 Hz`, 2-5 Hz step,
- also scan around `fr / 2` (same +/-100 Hz window and 2-5 Hz step), to
  test for second-harmonic (2f) electrostrictive excitation.

See `excitation_plan.csv` for the per-board Stage 1 bands and the
parametrized Stage 2 rule (Stage 2 bands are centered on the *measured*
`fr`, which is not known until Stage 1 has been run on that board).

## 6. Per-frequency-point procedure

1. Set the condition (frequency, Vac_peak, Vdc).
2. Settle 0.5 s.
3. Record 2.0 s.
4. Save the raw microphone waveform.
5. Extract the measured DUT voltage (from the SENSE+/SENSE- capture).
6. Extract acoustic amplitude at `f`.
7. Extract acoustic amplitude at `2f`.

See `data_schema.csv` for the exact fields this produces and
`run_protocol.md` for the full session-level procedure this step sits
inside of.

### Amplifier-fallback trigger

Stop and flag for review (do not automatically add an amplifier — this
design only records the fallback spec, per section 8) if, while direct-driving
from the function generator, any of the following is observed in the
measured `V_DUT` waveform:

- **amplitude collapse**: measured `V_DUT` amplitude fails to track the
  commanded generator level as frequency or drive level increases (e.g.
  drops by a large fraction of the expected value with no corresponding
  drop in generator setting),
- **clipping**: the captured waveform is visibly flat-topped rather than
  sinusoidal,
- **current-limit behavior**: the function generator indicates an overload
  / current-limit condition, or `V_DUT` fails to rise with generator
  amplitude at the top of its range.

## 7. Background noise

At the start of **every measurement session**, before any board is driven:

- record at least 10 s of background noise from the microphone with the
  function generator off.

Store this alongside the session's data (see `data_schema.csv`,
`background_reference_id`) so every measured acoustic amplitude in that
session can be compared against the actual noise floor it was taken
against.

## 8. Grounding

- Generator ground = DRIVE- = oscilloscope reference. This is a single
  shared ground node for the baseline (direct function-generator drive)
  setup.
- **Do not float a grounded oscilloscope by disconnecting protective
  earth.** This is a shock hazard and is not needed here, since the
  baseline drive is not floating.
- **If a future floating amplifier is introduced, require a proper
  differential or isolated measurement method** (isolated probe, isolated
  scope input, or a true differential probe across SENSE+/SENSE-) instead
  of lifting ground on any instrument. This design does not select or use
  a floating amplifier.

## 9. Commissioning-only current shunt

An optional 0.1 ohm low-side shunt may be inserted in the DRIVE- return
path **for commissioning only**, to cross-check `I_peak` against the
predicted value from section 3.

**Caveat:** inserting the shunt breaks the "DRIVE- = ground" identity that
the single-ended `V_DUT` measurement in section 1 relies on — the shunt's
own voltage drop appears between true generator ground and the board's
DRIVE-/SENSE- node while current flows. Treat shunt-based current
measurement as a **separate calibration step**: measure directly across the
shunt for that step, then remove the shunt before resuming normal
`V_DUT` / acoustic data collection runs.

## 10. Files in this directory (v0.3.0-D)

| file | contents |
|---|---|
| `ELECTRICAL_MEASUREMENT_SETUP.md` | this file |
| `equipment_requirements.csv` | instrumentation list, required vs. optional, key specs |
| `excitation_plan.csv` | Stage 1 / Stage 2 frequency-sweep plan (updated to the 200 Hz-20 kHz, fr +/-100 Hz protocol) |
| `measurement_geometry.csv` | microphone (and optional LDV) position relative to PCB center |
| `run_protocol.md` | full session-level operating procedure |
| `data_schema.csv` | field-by-field schema for the recorded per-run / per-frequency-point data |

## 11. Open items — not decided here

- No external amplifier is selected or purchased; only its fallback spec is
  recorded (the "external power amplifier (fallback only)" row of
  `equipment_requirements.csv`).
- No commercial MLCC part numbers are chosen; capacitor identity remains
  `REF` / `TBD-n` per `experiment_matrix_template.csv`.
- Exact microphone/preamp model, oscilloscope model, and function generator
  model are equipment decisions left to `equipment_requirements.csv`'s
  spec rows, not fixed here.

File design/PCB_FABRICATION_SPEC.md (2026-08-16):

# PCB fabrication and ordering specification — v0.3.0-C

## Status — read this first

This document is a **layout and ordering specification**, not a Gerber
package. It is meant to be handed to an EDA tool (KiCad / Altium / Eagle) to
draw the board. **Do not generate, export, or submit Gerbers / production
files from this document alone.** Before ordering:

1. Build the layout in an EDA tool from the geometry in this spec and
   `pcb_coordinates.csv`.
2. Run DRC against the target fab's capability (see "Manufacturing
   constraints" below).
3. Visually review the layout (copper, silkscreen, drill, outline) against
   this spec.

Only after that visual/DRC review should Gerbers be generated and an order
placed. No Gerbers exist as part of this deliverable.

This spec does not change the numerical model. It translates the already
finalized experimental design (`pcb_variants.md`, `PRE_PURCHASE_DESIGN.md`,
v0.2.0 simulation results) into orderable PCB designs.

## 1. Relationship to the experimental design

`pcb_variants.md` (v0.3.0) defined three experimental roles: S90 (primary
strong-response board), W90 (position-control), S0 (orientation-control).
This spec fabricates **five PCB designs**, because S90 is produced in three
MLCC footprint sizes to additionally check whether package size itself
affects the response, while W90 and S0 use a single footprint (0603) to
match whatever reference MLCC package is used for position/orientation
validation:

| variant | role | footprint | MLCC center (mm) | long-axis orientation |
|---|---|---|---|---|
| S90-0402 | primary, strong-response | 0402 | (50, 10) | 90 deg |
| S90-0603 | primary, strong-response | 0603 | (50, 10) | 90 deg |
| S90-0805 | primary, strong-response | 0805 | (50, 10) | 90 deg |
| W90-0603 | position-control | 0603 | (20, 20) | 90 deg |
| S0-0603  | orientation-control | 0603 | (50, 10) | 0 deg |

See `pcb_variants.csv` for the machine-readable version of this table and
`pcb_coordinates.csv` for full pad-level geometry.

## 2. Coordinate convention

- Origin: bottom-left corner of the board.
- `x`: 0-100 mm, the long (100 mm) direction.
- `y`: 0-40 mm, the short (40 mm) direction.
- Orientation 0 deg: MLCC long axis (the axis through its two terminals)
  parallel to `x`.
- Orientation 90 deg: MLCC long axis parallel to `y`.

This matches the `x/a`, `y/b`, `orientation_deg` convention already used by
the simulation (`model.py`, `coupling.py`) and by `pcb_variants.md`.

## 3. Shared board specification (all five variants)

| item | value |
|---|---|
| Material | FR-4 |
| Layers | 2 |
| Outline | 100 x 40 mm |
| Thickness | 1.0 mm |
| Copper weight | 1 oz (outer layers) |
| Surface finish | ENIG |
| Copper pours | none |
| Bottom-layer copper | none (component/routing on top layer only) |
| Vias | none |
| Mounting holes | 4x NPTH, 3.2 mm diameter |
| Mounting hole locations | (5, 5), (95, 5), (5, 35), (95, 35) mm |

The mounting holes are unplated (NPTH) and identical across all five
variants, so all boards mount on the same fixture with the same compliant
corner standoffs described in `pcb_variants.md`.

## 4. MLCC footprints

Each variant uses **only its own nominal single-size footprint** for its
named package. Do not design a universal/combined pad pattern sized to fit
multiple packages — that changes solder-joint fillet geometry and effective
mechanical stiffness/coupling, which this experiment depends on being
representative of a normal, single-size solder joint.

The land-pattern dimensions below are **nominal/typical IPC-7351 "Nominal"
(Level B) numbers, provided as a layout starting point.** They must be
confirmed against the actual footprint library used in the EDA tool (e.g.
KiCad's standard `*_1005Metric` / `*_1608Metric` / `*_2012Metric` chip
footprints) before layout — do not hand-enter these into Gerbers directly.

| package | body size (L x W, mm) | pad size (mm) | pad pitch, center-to-center (mm) | reference courtyard (mm) |
|---|---|---|---|---|
| 0402 (1005 metric) | 1.0 x 0.5 | 0.6 x 0.6 | 1.0 | ~1.6 x 0.8 |
| 0603 (1608 metric) | 1.6 x 0.8 | 0.9 x 1.0 | 1.6 | ~2.4 x 1.2 |
| 0805 (2012 metric) | 2.0 x 1.25 | 1.2 x 1.45 | 1.9 | ~2.9 x 1.8 |

Two-pad footprint per variant, centered on the MLCC center coordinate and
rotated per its orientation (pads split along the long axis by the pitch
above). Computed pad centers for all five variants are in
`pcb_coordinates.csv`.

## 5. Electrical routing

### Four-wire (Kelvin) edge interface

All external electrical contact is a row of four solder pads near the left
edge (`x` small), in this order: **DRIVE+, SENSE+, SENSE-, DRIVE-**. No
connector component (header, JST, etc.) is placed on the board — wires are
soldered directly to these pads, so no connector mass/stiffness is added to
the vibrating structure.

Suggested reference pad row (to be confirmed in EDA, not final):

| pad | x (mm) | y (mm) |
|---|---|---|
| DRIVE+ | 5 | 12.5 |
| SENSE+ | 5 | 17.5 |
| SENSE- | 5 | 22.5 |
| DRIVE- | 5 | 27.5 |

This keeps the whole interface within the `x <= 15 mm` edge keepout strip
(section 7) and clear of the two left mounting holes at (5, 5) and (5, 35)
by >= 7.5 mm.

### Trace widths

- DRIVE+ / DRIVE- traces: **0.5 mm**.
- SENSE+ / SENSE- traces: **0.2 mm**.

Both are comfortably above typical 2-layer fab minimum trace width
(~0.09-0.15 mm depending on fab) and well above what's needed to carry the
capacitive drive current `I_peak = 2*pi*f*C*V_peak` at these excitation
frequencies and voltages — trace width here is set by manufacturability and
robustness, not current-carrying capacity.

### Kelvin sensing rule (implements "DUT voltage must be measured directly
across the capacitor")

**SENSE+ and SENSE- must originate directly at the MLCC pad copper**, not
as a branch off the DRIVE+/DRIVE- trace at some other point. If SENSE+ taps
the DRIVE+ trace anywhere between the edge and the MLCC, the measured
voltage includes the DRIVE trace's own resistive/inductive drop and the
"direct across the capacitor" principle is violated. Route SENSE+/SENSE- as
separate, thin (0.2 mm) traces from the MLCC pad back to the edge, alongside
but not merged with, the DRIVE traces.

Because MLCC position differs by variant (S90/S0 at x=50 mm, W90 at
x=20 mm), trace lengths from the edge interface to the MLCC differ across
variants. This is expected and acceptable: it is internal copper (negligible
added mass), not external wiring, so it does not violate the "wires near the
edge, not near the MLCC" principle, which concerns the mass/stiffness loading
of the external lead wires at their solder point — that solder point (the
edge pad row) is identical across all variants.

## 6. Design rule: no connectors, no vias, no bottom copper, no pours

- No connector components (headers, JST, etc.) anywhere on the board.
- No vias — this is a single-side (top layer) routed design; the bottom
  layer carries no copper at all.
- No copper pour / plane on either layer.

These rules keep the board's mass and stiffness distribution close to the
bare-FR4 assumption in the simulation (`README.md` section 1), and avoid an
unmodeled ground-plane or via-field stiffening effect near the vibrating
region.

## 7. Keepout / active-region rule

Split the board into two regions along `x`:

- **Edge strip, `x` in [0, 15] mm**: the four-wire interface pads, their
  immediate escape traces, and board/variant identification silkscreen
  (e.g. "S90-0603", a rev letter) are allowed here.
- **Active region, `x` in (15, 100] mm, full `y`**: copper is limited to
  the DRIVE/SENSE traces routed to the MLCC and the MLCC footprint pads
  themselves. No copper pour, no additional components, no fiducials, and
  no non-essential silkscreen (logos, outlines, revision text) are placed
  in the active region.

This keeps unmodeled copper/silkscreen mass out of the part of the board
where the plate's mode shapes have significant amplitude.

## 8. Manufacturing constraints check (informational, confirm at order time)

| item | this design | typical 2-layer FR-4 fab capability | margin |
|---|---|---|---|
| min trace width | 0.2 mm (sense) | ~0.09-0.15 mm | comfortable |
| min trace spacing | not yet routed — confirm in EDA | ~0.09-0.15 mm | confirm after layout |
| board thickness | 1.0 mm | standard range ~0.4-2.0 mm | within range |
| NPTH hole diameter | 3.2 mm | standard min NPTH ~0.3 mm | comfortable |
| layers | 2 | standard | n/a |
| surface finish | ENIG | standard option | n/a |

These are typical prototype-fab figures, not a specific fab's guaranteed
capability — reconfirm against the chosen fab house's current design rules
before finalizing the layout. See `jlcpcb_order_settings.csv` for the
JLCPCB-specific version of this check.

## 9. Files in this directory (v0.3.0-C additions)

| file | contents |
|---|---|
| `PCB_FABRICATION_SPEC.md` | this file |
| `pcb_variants.csv` | one row per orderable PCB design, fabrication-level attributes |
| `pcb_coordinates.csv` | MLCC center, orientation, footprint pitch, and computed pad coordinates per variant |
| `jlcpcb_order_settings.csv` | shared order-form settings and capability checks |
| `pcb_quantity_plan.csv` | planned order quantity per variant, with the reasoning split out |

(`pcb_variants.md`, `pcb_coordinates.csv` from v0.3.0, `PRE_PURCHASE_DESIGN.md`,
`excitation_plan.csv`, `experiment_matrix_template.csv` remain the
experimental-design layer this spec builds on. Note `pcb_coordinates.csv` is
superseded by the v0.3.0-C version in this same path, now at footprint-level
granularity.)

## 10. Open items before ordering

- Draw the layout in an EDA tool and run DRC (this spec is not a substitute).
- Confirm the four IPC nominal footprints against the actual EDA library
  parts used.
- Decide solder mask color, silkscreen color, and panelization with the fab
  (cosmetic / logistic, does not affect the experiment).
- Confirm current fab capability numbers in section 8 against the specific
  fab house and process selected at order time.

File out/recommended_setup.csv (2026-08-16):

parameter | recommended value
PCB length | 100 mm
PCB width | 40 mm
PCB thickness | 0.8 mm
MLCC x-position | x/a = 0.50
MLCC y-position | y/b = 0.25
MLCC orientation | 90 deg
main frequency range | 200-3000 Hz
resonance frequencies | 439, 872, 919, 1834
strong-response condition | x/a=0.50, y/b=0.25, orientation=90 deg (peak=171)
control condition | x/a=0.20, y/b=0.50, orientation=90 deg (peak=38.1)

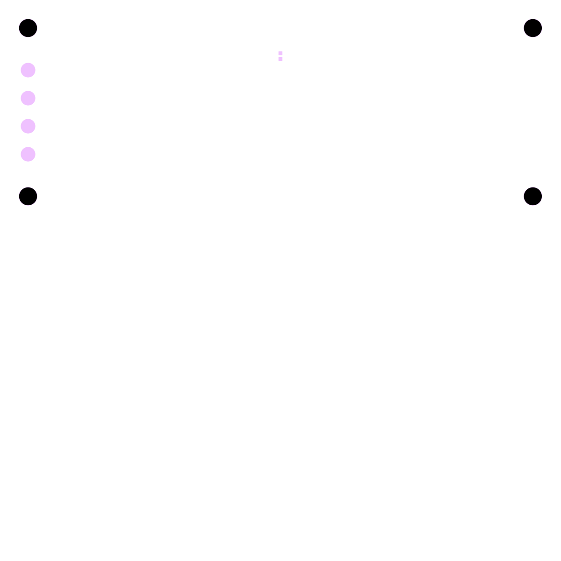
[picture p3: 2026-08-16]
pcb/S90-0402/manufacturing/gerber_verification/S90-0402_solder_mask.png

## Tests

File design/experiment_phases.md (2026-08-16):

# Experiment phases — v0.3.0-E

This defines Phase 0 (resonance identification) through Phase 8 of the final
pre-purchase experiment plan. It builds on `pcb_variants.md` (v0.3.0),
`PCB_FABRICATION_SPEC.md` (v0.3.0-C), and `ELECTRICAL_MEASUREMENT_SETUP.md` /
`run_protocol.md` (v0.3.0-D) without changing any of them. The concrete,
row-level plan is `final_experiment_matrix.csv`; this file is the narrative
walkthrough of how that matrix was built, including the judgment calls made
to turn the phase descriptions into concrete rows.

## Conventions carried forward, unchanged

- All AC amplitudes are V_peak (`ELECTRICAL_MEASUREMENT_SETUP.md` section 2).
- The controlled voltage is the **actual measured** `V_DUT`, not the
  generator setting. The operator adjusts the generator so measured Vac is
  within **+/-2%** of the target value in every row below.
- Voltage budget: `|Vdc| + Vac_peak <= capacitor rated voltage`, checked
  before every run (`ELECTRICAL_MEASUREMENT_SETUP.md` section 2). All
  target levels used in Phases 1-8 (max |Vdc|+Vac_peak = 2.8+0.10 = 2.9 V in
  Phase 8) are comfortably under every rated voltage in the population
  (10-50 V), so no combination needs to be skipped for this design.
- Per-measurement-point procedure is unchanged: settle 0.5 s, record 2.0 s,
  save the raw microphone waveform, record actual `V_DUT`, extract acoustic
  response at `f` and at `2f` (`run_protocol.md` section 5).
- Record at least 10 s of background noise at the start of every session
  (`run_protocol.md` section 2).
- Do not invent numerical values for fr1/fr2/fr3 anywhere in this design —
  every row that depends on them carries a symbolic label
  (`fr1`, `fr2`, `fr3`, `fr1/2`, `fr2/2`, `fr3/2`, `fr_star`, `fr_star/2`)
  and an explicit "measured value ... not yet available" placeholder instead
  of a number.

## Phase 0 — Resonance identification (must run first)

- Specimen: **S90-0603-R-01** only.
- Vdc = 0 V, measured Vac = 0.02 V_peak.
- 200-3000 Hz at 25 Hz step, then 3000-20000 Hz at 100 Hz step.
- Output: identify the three primary, well-separated resonances within
  200-3000 Hz as **fr1, fr2, fr3**, and the strongest of the three as
  **fr_star**. The 3000-20000 Hz band is scanned for context but does not
  define fr1/fr2/fr3 (those are defined "within 200-3000 Hz" per spec).
- `fr1, fr2, fr3, fr1/2, fr2/2, fr3/2` become **the standard
  six-frequency set** used by every phase below.

This is a single run on a single specimen. It is not repeated per board or
per phase — see the go/no-go gate (`go_no_go_criteria.md`) for how
resonance *reproducibility* across the other R specimens is checked without
re-running a full broad sweep on each one.

## Phase 1 — Reference position/orientation validation

- Specimens: all **9** reference boards — S90-0603-R-01/02/03,
  W90-0603-R-01/02/03, S0-0603-R-01/02/03.
- Condition: **the standard six-frequency set**, Vac = 0.10 V_peak,
  Vdc = 0 V.

**Judgment call**: the phase description ("Reference R on S90, W90, and S0,
3 physical replicates each. Purpose: validate position and orientation
effects") does not restate a frequency/voltage condition. Since section
"All main MLCC-property comparisons use ... the standard six-frequency set"
immediately follows it, and Phase 1's own purpose is a comparison (S90 vs
W90 for position, S90 vs S0 for orientation) that needs to be measured on
the same footing as every later comparison, this design applies the
standard condition (0.10 V_peak / 0 V / six-frequency set) to Phase 1 as
well. This is stated explicitly here so it can be corrected if a different
condition was intended for Phase 1 specifically.

54 rows (9 specimens x 6 frequencies), all new measurements.

## Go/no-go gate

Placed here, after Phase 1 and before Phase 2. See `go_no_go_criteria.md`
for the full operationalized criteria. Do not proceed past this point
without a "go."

## Phase 2 — Package comparison (P1 0402 vs R 0603 vs P2 0805)

- New specimens: S90-0402-P1-01/02/03, S90-0805-P2-01/02/03 (6 specimens x
  6 frequencies = 36 new rows).
- Reused: the S90-0603-R-01/02/03 data already collected in Phase 1 serves
  as the 0603 arm (18 rows, tagged `Reused from Phase 1` in the matrix) —
  no new physical measurement, since it is the same condition on the same
  specimens.
- Condition: standard six-frequency set, Vac = 0.10 V_peak, Vdc = 0 V.

## Phase 3 — Capacitance comparison (C1 0.1uF vs R 1uF vs C2 10uF)

- New specimens: S90-0603-C1-01/02, S90-0603-C2-01/02 (4 specimens x 6
  frequencies = 24 new rows).
- Reused: S90-0603-R-01/02/03 from Phase 1 (18 rows) as the 1 uF arm.
- Condition: standard six-frequency set, Vac = 0.10 V_peak, Vdc = 0 V.

Note the group sizes are intentionally unequal (2 replicates for C1/C2,
3 for R) — this is expected in a non-factorial, reuse-driven design.

## Phase 4 — Rated-voltage comparison (R 10V vs V1 16V vs V2 25V vs V3 50V)

- New specimens: S90-0603-V1-01/02, V2-01/02, V3-01/02 (6 specimens x 6
  frequencies = 36 new rows).
- Reused: S90-0603-R-01/02/03 from Phase 1 (18 rows) as the 10 V arm.
- Condition: standard six-frequency set, Vac = 0.10 V_peak, Vdc = 0 V.

## Phase 5 — Dielectric comparison (P2 X5R vs D1 X7R, matched 0805/1uF/10V)

- New specimens: S90-0805-D1-01/02 (2 specimens x 6 frequencies = 12 new
  rows).
- Reused: S90-0805-P2-01/02/03 from Phase 2 (18 rows) as the X5R arm — same
  specimens, same condition, already measured there.
- Condition: standard six-frequency set, Vac = 0.10 V_peak, Vdc = 0 V.

## Phase 6 — C0G negative control (N1)

- Specimens: S90-0603-N1-01/02.
- **Required** baseline: standard six-frequency set, Vac = 0.10 V_peak,
  Vdc = 0 V (12 rows, new).
- **Optional** sensitivity run: same 2 specimens, same standard
  six-frequency set (assumed — the spec does not restate a frequency set for
  the optional run, so this design reuses the standard one for
  comparability), at Vac = 0.50 V_peak, **only if** the baseline response is
  below reliable acoustic SNR (12 rows, optional, new).
- **Do not treat the optional 0.50 V_peak result as a direct quantitative
  comparison with the X5R parts** measured at 0.10 V_peak elsewhere in this
  design — it exists only to confirm C0G shows negligible response even
  when pushed harder, not to be plotted on the same amplitude axis as the
  X5R comparisons.

## Phase 7 — AC-amplitude sweep (3 reference specimens)

- Specimens: S90-0603-R-01/02/03.
- Frequencies: `fr_star` and `fr_star/2` only (not the full six-set).
- Vdc = 0 V. Vac = 0.05, 0.10, 0.25, 0.50 V_peak.
- 24 conditions (3 specimens x 2 frequencies x 4 levels).

**Reuse**: because `fr_star` is by definition one of {fr1, fr2, fr3} and
`fr_star/2` is one of {fr1/2, fr2/2, fr3/2}, the Vac = 0.10 V_peak / Vdc = 0 V
point at both frequencies, on these same 3 specimens, is structurally
guaranteed to already exist in the Phase 1 data — regardless of which of
fr1/fr2/fr3 turns out to be fr_star. Those 6 rows are tagged `Reused from
Phase 1`; the other 18 (Vac = 0.05, 0.25, 0.50) are new.

## Phase 8 — DC-bias sweep (3 reference specimens)

- Specimens: S90-0603-R-01/02/03.
- Frequencies: `fr_star` and `fr_star/2`.
- Vac = 0.10 V_peak. Vdc = 0, 1, 2, 2.8 V.
- 24 conditions (3 specimens x 2 frequencies x 4 levels).

**Reuse**: by the same argument as Phase 7, the Vdc = 0 V point (at
Vac = 0.10 V_peak, both frequencies, same 3 specimens) is structurally
identical to a Phase 1 measurement. Those 6 rows are tagged `Reused from
Phase 1`; the other 18 (Vdc = 1, 2, 2.8) are new.

**Note**: the single condition Vac = 0.10 V_peak / Vdc = 0 V at `fr_star`
and `fr_star/2` on S90-0603-R-01/02/03 is therefore shared by Phase 1,
Phase 7, and Phase 8 simultaneously — it is measured once, in Phase 1, and
referenced by both later phases.

## Row totals (from `final_experiment_matrix.csv`)

| phase | rows | new | reused |
|---|---|---|---|
| 0 - resonance ID | 2 | 2 | 0 |
| 1 - position/orientation | 54 | 54 | 0 |
| 2 - package | 54 | 36 | 18 (Phase 1) |
| 3 - capacitance | 42 | 24 | 18 (Phase 1) |
| 4 - rated voltage | 54 | 36 | 18 (Phase 1) |
| 5 - dielectric | 30 | 12 | 18 (Phase 2) |
| 6 - C0G control | 24 (12 required + 12 optional) | 24 | 0 |
| 7 - AC-amplitude sweep | 24 | 18 | 6 (Phase 1) |
| 8 - DC-bias sweep | 24 | 18 | 6 (Phase 1) |
| **total** | **308** | **224** | **84** |

212 rows are both new and required (224 new minus the 12 new-but-optional
Phase 6 rows).

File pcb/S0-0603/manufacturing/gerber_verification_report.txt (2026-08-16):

Gerber verification report for S0-0603

Layer renders (from actual exported Gerbers via kicad-cli pcb export svg):
  [OK] top_copper
  [OK] solder_mask
  [OK] silkscreen
  [OK] edge_cuts
  [OK] composite_top

Programmatic checks (parsed directly from the Gerber/drill files):
[PASS] gerber_outline_100x40mm  {'x_min': 0.0, 'x_max': 100.0, 'y_min': -4.6e-05, 'y_max': 40.0}
[PASS] drill_centers_exact  got [(5.0, 5.0), (5.0, 35.0), (95.0, 5.0), (95.0, 35.0)], expected [(5.0, 5.0), (5.0, 35.0), (95.0, 5.0), (95.0, 35.0)]
[PASS] no_copper_outside_board  {'x_min': 4.6e-05, 'x_max': 50.8, 'y_min': -4.6e-05, 'y_max': 27.5}
[PASS] mlcc_location_in_gerber  pad1=(49.2, 10.0) pad2=(50.8, 10.0)
[PASS] no_missing_trace_gerber_nonempty  34 coord ops

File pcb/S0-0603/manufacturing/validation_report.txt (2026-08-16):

Custom geometry validator report for S0-0603
NOT KiCad DRC -- kicad-cli/pcbnew unavailable in this environment.

[PASS] board_dimensions_100x40mm  x:[0.0,100.0] y:[0.0,40.0]
[PASS] mounting_hole_count  found 4
[PASS] mounting_hole_centers_exact  got [(5.0, 5.0), (5.0, 35.0), (95.0, 5.0), (95.0, 35.0)], expected [(5.0, 5.0), (5.0, 35.0), (95.0, 5.0), (95.0, 35.0)]
[PASS] mounting_hole_diameter_3.2mm  [('3.2', '3.2', '3.2'), ('3.2', '3.2', '3.2'), ('3.2', '3.2', '3.2'), ('3.2', '3.2', '3.2')]
[PASS] mlcc_correct_footprint_used  found ['SC4:C_0603_Local']
[PASS] mlcc_center_exact  got (50.0,10.0) expected (50.0,10.0)
[PASS] mlcc_orientation_exact  got 0.0 expected 0
[PASS] no_vias  found 0
[PASS] no_copper_zones  found 0
[PASS] no_bcu_tracks  found 0
[PASS] no_bcu_in_pad_layers  found 0
[PASS] trace_widths_only_0.5_or_0.2mm  widths found: [0.2, 0.5]
[PASS] drive_and_sense_segments_present  0.5mm segs=7, 0.2mm segs=7
[PASS] four_interface_pads_reach_intended_mlcc_terminal  DRIVE+->net1 vs MLCC(+)->net1 OK; SENSE+->net1 vs MLCC(+)->net1 OK; SENSE-->net2 vs MLCC(-)->net2 OK; DRIVE-->net2 vs MLCC(-)->net2 OK
[PASS] no_unintended_cross_net_shorts  conflicting segment pairs: 0

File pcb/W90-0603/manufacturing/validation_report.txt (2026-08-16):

Custom geometry validator report for W90-0603
NOT KiCad DRC -- kicad-cli/pcbnew unavailable in this environment.

[PASS] board_dimensions_100x40mm  x:[0.0,100.0] y:[0.0,40.0]
[PASS] mounting_hole_count  found 4
[PASS] mounting_hole_centers_exact  got [(5.0, 5.0), (5.0, 35.0), (95.0, 5.0), (95.0, 35.0)], expected [(5.0, 5.0), (5.0, 35.0), (95.0, 5.0), (95.0, 35.0)]
[PASS] mounting_hole_diameter_3.2mm  [('3.2', '3.2', '3.2'), ('3.2', '3.2', '3.2'), ('3.2', '3.2', '3.2'), ('3.2', '3.2', '3.2')]
[PASS] mlcc_correct_footprint_used  found ['SC4:C_0603_Local']
[PASS] mlcc_center_exact  got (20.0,20.0) expected (20.0,20.0)
[PASS] mlcc_orientation_exact  got 90.0 expected 90
[PASS] no_vias  found 0
[PASS] no_copper_zones  found 0
[PASS] no_bcu_tracks  found 0
[PASS] no_bcu_in_pad_layers  found 0
[PASS] trace_widths_only_0.5_or_0.2mm  widths found: [0.2, 0.5]
[PASS] drive_and_sense_segments_present  0.5mm segs=6, 0.2mm segs=6
[PASS] four_interface_pads_reach_intended_mlcc_terminal  DRIVE+->net1 vs MLCC(+)->net1 OK; SENSE+->net1 vs MLCC(+)->net1 OK; SENSE-->net2 vs MLCC(-)->net2 OK; DRIVE-->net2 vs MLCC(-)->net2 OK
[PASS] no_unintended_cross_net_shorts  conflicting segment pairs: 0

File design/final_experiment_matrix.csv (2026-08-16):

phase | phase_name | specimen_id | variant | capacitor_role | freq_label | freq_spec | vac_peak_target_v | vdc_target_v | required_or_optional | new_measurement_or_reused | purpose
0 | Resonance identification | S90-0603-R-01 | S90-0603 | R | broad-low | 200-3000 Hz, 25 Hz step | 0.02 | 0 | required | New | locate fr1/fr2/fr3 (defines the standard six-frequency set used by every later phase)
0 | Resonance identification | S90-0603-R-01 | S90-0603 | R | broad-high | 3000-20000 Hz, 100 Hz step | 0.02 | 0 | required | New | locate any resonances above 3000 Hz for context (fr1/fr2/fr3 are defined within 200-3000 Hz only)
1 | Reference position/orientation validation | S90-0603-R-01 | S90-0603 | R | fr1 | measured value from Phase 0 - not yet available | 0.1 | 0 | required | New | validate position effect (S90 vs W90) and orientation effect (S90 vs S0)
1 | Reference position/orientation validation | S90-0603-R-01 | S90-0603 | R | fr2 | measured value from Phase 0 - not yet available | 0.1 | 0 | required | New | validate position effect (S90 vs W90) and orientation effect (S90 vs S0)
1 | Reference position/orientation validation | S90-0603-R-01 | S90-0603 | R | fr3 | measured value from Phase 0 - not yet available | 0.1 | 0 | required | New | validate position effect (S90 vs W90) and orientation effect (S90 vs S0)
1 | Reference position/orientation validation | S90-0603-R-01 | S90-0603 | R | fr1/2 | measured value from Phase 0 - not yet available | 0.1 | 0 | required | New | validate position effect (S90 vs W90) and orientation effect (S90 vs S0)
1 | Reference position/orientation validation | S90-0603-R-01 | S90-0603 | R | fr2/2 | measured value from Phase 0 - not yet available | 0.1 | 0 | required | New | validate position effect (S90 vs W90) and orientation effect (S90 vs S0)
1 | Reference position/orientation validation | S90-0603-R-01 | S90-0603 | R | fr3/2 | measured value from Phase 0 - not yet available | 0.1 | 0 | required | New | validate position effect (S90 vs W90) and orientation effect (S90 vs S0)
1 | Reference position/orientation validation | S90-0603-R-02 | S90-0603 | R | fr1 | measured value from Phase 0 - not yet available | 0.1 | 0 | required | New | validate position effect (S90 vs W90) and orientation effect (S90 vs S0)
1 | Reference position/orientation validation | S90-0603-R-02 | S90-0603 | R | fr2 | measured value from Phase 0 - not yet available | 0.1 | 0 | required | New | validate position effect (S90 vs W90) and orientation effect (S90 vs S0)
1 | Reference position/orientation validation | S90-0603-R-02 | S90-0603 | R | fr3 | measured value from Phase 0 - not yet available | 0.1 | 0 | required | New | validate position effect (S90 vs W90) and orientation effect (S90 vs S0)
1 | Reference position/orientation validation | S90-0603-R-02 | S90-0603 | R | fr1/2 | measured value from Phase 0 - not yet available | 0.1 | 0 | required | New | validate position effect (S90 vs W90) and orientation effect (S90 vs S0)
1 | Reference position/orientation validation | S90-0603-R-02 | S90-0603 | R | fr2/2 | measured value from Phase 0 - not yet available | 0.1 | 0 | required | New | validate position effect (S90 vs W90) and orientation effect (S90 vs S0)
1 | Reference position/orientation validation | S90-0603-R-02 | S90-0603 | R | fr3/2 | measured value from Phase 0 - not yet available | 0.1 | 0 | required | New | validate position effect (S90 vs W90) and orientation effect (S90 vs S0)
1 | Reference position/orientation validation | S90-0603-R-03 | S90-0603 | R | fr1 | measured value from Phase 0 - not yet available | 0.1 | 0 | required | New | validate position effect (S90 vs W90) and orientation effect (S90 vs S0)
1 | Reference position/orientation validation | S90-0603-R-03 | S90-0603 | R | fr2 | measured value from Phase 0 - not yet available | 0.1 | 0 | required | New | validate position effect (S90 vs W90) and orientation effect (S90 vs S0)
1 | Reference position/orientation validation | S90-0603-R-03 | S90-0603 | R | fr3 | measured value from Phase 0 - not yet available | 0.1 | 0 | required | New | validate position effect (S90 vs W90) and orientation effect (S90 vs S0)
1 | Reference position/orientation validation | S90-0603-R-03 | S90-0603 | R | fr1/2 | measured value from Phase 0 - not yet available | 0.1 | 0 | required | New | validate position effect (S90 vs W90) and orientation effect (S90 vs S0)
1 | Reference position/orientation validation | S90-0603-R-03 | S90-0603 | R | fr2/2 | measured value from Phase 0 - not yet available | 0.1 | 0 | required | New | validate position effect (S90 vs W90) and orientation effect (S90 vs S0)
1 | Reference position/orientation validation | S90-0603-R-03 | S90-0603 | R | fr3/2 | measured value from Phase 0 - not yet available | 0.1 | 0 | required | New | validate position effect (S90 vs W90) and orientation effect (S90 vs S0)
1 | Reference position/orientation validation | W90-0603-R-01 | W90-0603 | R | fr1 | measured value from Phase 0 - not yet available | 0.1 | 0 | required | New | validate position effect (S90 vs W90) and orientation effect (S90 vs S0)
1 | Reference position/orientation validation | W90-0603-R-01 | W90-0603 | R | fr2 | measured value from Phase 0 - not yet available | 0.1 | 0 | required | New | validate position effect (S90 vs W90) and orientation effect (S90 vs S0)
1 | Reference position/orientation validation | W90-0603-R-01 | W90-0603 | R | fr3 | measured value from Phase 0 - not yet available | 0.1 | 0 | required | New | validate position effect (S90 vs W90) and orientation effect (S90 vs S0)
1 | Reference position/orientation validation | W90-0603-R-01 | W90-0603 | R | fr1/2 | measured value from Phase 0 - not yet available | 0.1 | 0 | required | New | validate position effect (S90 vs W90) and orientation effect (S90 vs S0)
1 | Reference position/orientation validation | W90-0603-R-01 | W90-0603 | R | fr2/2 | measured value from Phase 0 - not yet available | 0.1 | 0 | required | New | validate position effect (S90 vs W90) and orientation effect (S90 vs S0)
1 | Reference position/orientation validation | W90-0603-R-01 | W90-0603 | R | fr3/2 | measured value from Phase 0 - not yet available | 0.1 | 0 | required | New | validate position effect (S90 vs W90) and orientation effect (S90 vs S0)
1 | Reference position/orientation validation | W90-0603-R-02 | W90-0603 | R | fr1 | measured value from Phase 0 - not yet available | 0.1 | 0 | required | New | validate position effect (S90 vs W90) and orientation effect (S90 vs S0)
1 | Reference position/orientation validation | W90-0603-R-02 | W90-0603 | R | fr2 | measured value from Phase 0 - not yet available | 0.1 | 0 | required | New | validate position effect (S90 vs W90) and orientation effect (S90 vs S0)
1 | Reference position/orientation validation | W90-0603-R-02 | W90-0603 | R | fr3 | measured value from Phase 0 - not yet available | 0.1 | 0 | required | New | validate position effect (S90 vs W90) and orientation effect (S90 vs S0)
1 | Reference position/orientation validation | W90-0603-R-02 | W90-0603 | R | fr1/2 | measured value from Phase 0 - not yet available | 0.1 | 0 | required | New | validate position effect (S90 vs W90) and orientation effect (S90 vs S0)
1 | Reference position/orientation validation | W90-0603-R-02 | W90-0603 | R | fr2/2 | measured value from Phase 0 - not yet available | 0.1 | 0 | required | New | validate position effect (S90 vs W90) and orientation effect (S90 vs S0)
1 | Reference position/orientation validation | W90-0603-R-02 | W90-0603 | R | fr3/2 | measured value from Phase 0 - not yet available | 0.1 | 0 | required | New | validate position effect (S90 vs W90) and orientation effect (S90 vs S0)
1 | Reference position/orientation validation | W90-0603-R-03 | W90-0603 | R | fr1 | measured value from Phase 0 - not yet available | 0.1 | 0 | required | New | validate position effect (S90 vs W90) and orientation effect (S90 vs S0)
1 | Reference position/orientation validation | W90-0603-R-03 | W90-0603 | R | fr2 | measured value from Phase 0 - not yet available | 0.1 | 0 | required | New | validate position effect (S90 vs W90) and orientation effect (S90 vs S0)
1 | Reference position/orientation validation | W90-0603-R-03 | W90-0603 | R | fr3 | measured value from Phase 0 - not yet available | 0.1 | 0 | required | New | validate position effect (S90 vs W90) and orientation effect (S90 vs S0)
1 | Reference position/orientation validation | W90-0603-R-03 | W90-0603 | R | fr1/2 | measured value from Phase 0 - not yet available | 0.1 | 0 | required | New | validate position effect (S90 vs W90) and orientation effect (S90 vs S0)
1 | Reference position/orientation validation | W90-0603-R-03 | W90-0603 | R | fr2/2 | measured value from Phase 0 - not yet available | 0.1 | 0 | required | New | validate position effect (S90 vs W90) and orientation effect (S90 vs S0)
1 | Reference position/orientation validation | W90-0603-R-03 | W90-0603 | R | fr3/2 | measured value from Phase 0 - not yet available | 0.1 | 0 | required | New | validate position effect (S90 vs W90) and orientation effect (S90 vs S0)
1 | Reference position/orientation validation | S0-0603-R-01 | S0-0603 | R | fr1 | measured value from Phase 0 - not yet available | 0.1 | 0 | required | New | validate position effect (S90 vs W90) and orientation effect (S90 vs S0)
1 | Reference position/orientation validation | S0-0603-R-01 | S0-0603 | R | fr2 | measured value from Phase 0 - not yet available | 0.1 | 0 | required | New | validate position effect (S90 vs W90) and orientation effect (S90 vs S0)
1 | Reference position/orientation validation | S0-0603-R-01 | S0-0603 | R | fr3 | measured value from Phase 0 - not yet available | 0.1 | 0 | required | New | validate position effect (S90 vs W90) and orientation effect (S90 vs S0)
1 | Reference position/orientation validation | S0-0603-R-01 | S0-0603 | R | fr1/2 | measured value from Phase 0 - not yet available | 0.1 | 0 | required | New | validate position effect (S90 vs W90) and orientation effect (S90 vs S0)
1 | Reference position/orientation validation | S0-0603-R-01 | S0-0603 | R | fr2/2 | measured value from Phase 0 - not yet available | 0.1 | 0 | required | New | validate position effect (S90 vs W90) and orientation effect (S90 vs S0)
1 | Reference position/orientation validation | S0-0603-R-01 | S0-0603 | R | fr3/2 | measured value from Phase 0 - not yet available | 0.1 | 0 | required | New | validate position effect (S90 vs W90) and orientation effect (S90 vs S0)
1 | Reference position/orientation validation | S0-0603-R-02 | S0-0603 | R | fr1 | measured value from Phase 0 - not yet available | 0.1 | 0 | required | New | validate position effect (S90 vs W90) and orientation effect (S90 vs S0)
1 | Reference position/orientation validation | S0-0603-R-02 | S0-0603 | R | fr2 | measured value from Phase 0 - not yet available | 0.1 | 0 | required | New | validate position effect (S90 vs W90) and orientation effect (S90 vs S0)
1 | Reference position/orientation validation | S0-0603-R-02 | S0-0603 | R | fr3 | measured value from Phase 0 - not yet available | 0.1 | 0 | required | New | validate position effect (S90 vs W90) and orientation effect (S90 vs S0)
1 | Reference position/orientation validation | S0-0603-R-02 | S0-0603 | R | fr1/2 | measured value from Phase 0 - not yet available | 0.1 | 0 | required | New | validate position effect (S90 vs W90) and orientation effect (S90 vs S0)
1 | Reference position/orientation validation | S0-0603-R-02 | S0-0603 | R | fr2/2 | measured value from Phase 0 - not yet available | 0.1 | 0 | required | New | validate position effect (S90 vs W90) and orientation effect (S90 vs S0)
1 | Reference position/orientation validation | S0-0603-R-02 | S0-0603 | R | fr3/2 | measured value from Phase 0 - not yet available | 0.1 | 0 | required | New | validate position effect (S90 vs W90) and orientation effect (S90 vs S0)
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

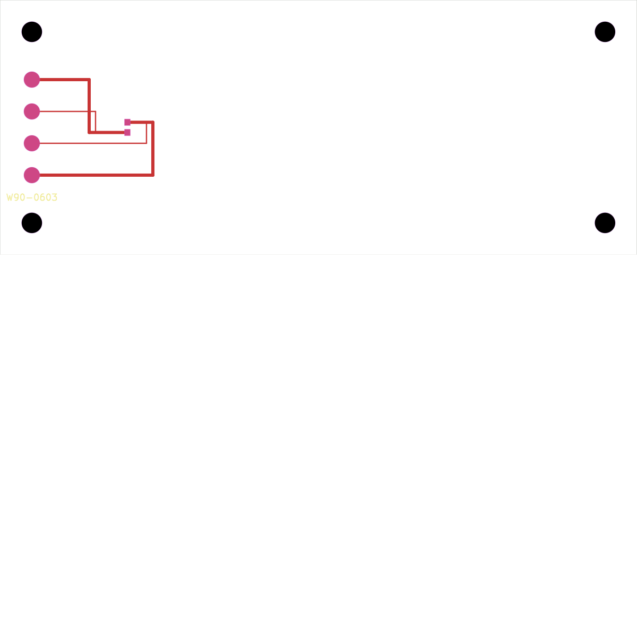
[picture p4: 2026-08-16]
pcb/W90-0603/manufacturing/gerber_verification/W90-0603_composite_top.png

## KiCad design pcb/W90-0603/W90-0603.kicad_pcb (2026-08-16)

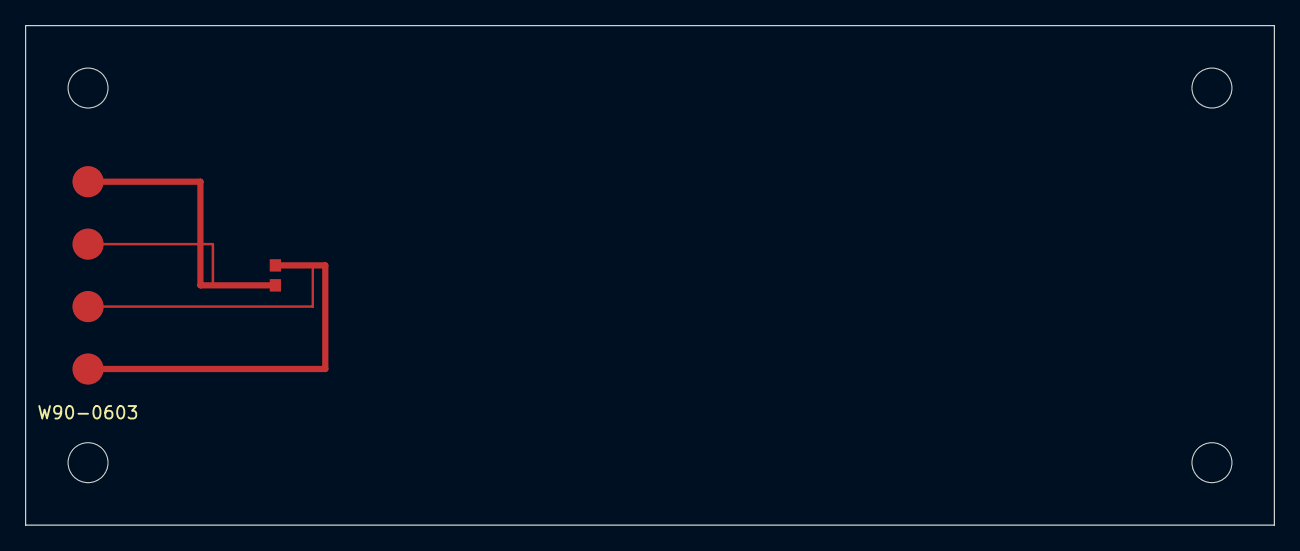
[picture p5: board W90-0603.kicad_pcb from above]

Board: 2 copper layers, 100.0 x 40.0 mm, 9 parts (0 on the bottom side), 2 nets.

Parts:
DRIVE+: EdgeContact; EdgeContact_2.5mm_Round
DRIVE-: EdgeContact; EdgeContact_2.5mm_Round
H1, H2, H3, H4: NPTH_3.2mm
MLCC1: C_0603; C_0603_Local
SENSE+: EdgeContact; EdgeContact_2.5mm_Round
SENSE-: EdgeContact; EdgeContact_2.5mm_Round

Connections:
DRIVE_SENSE_MINUS: DRIVE-.1, MLCC1.2, SENSE-.1
DRIVE_SENSE_PLUS: DRIVE+.1, MLCC1.1, SENSE+.1

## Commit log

2026-08-16 v0.1.0 — Baseline reduced-order model
2026-08-16 v0.2.0 - PCB robustness & final selection
    [pcb_candidate_comparison.csv]
2026-08-16 v0.3.0-A - Experimental setup architecture
    [excitation_plan.csv, experiment_matrix_template.csv, pcb_coordinates.csv]
2026-08-16 v0.3.0-C — PCB fabrication / ordering specification
    [jlcpcb_order_settings.csv, pcb_coordinates.csv, pcb_quantity_plan.csv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]
2026-08-16 v0.3.0-D — Electrical drive & measurement setup
    [data_schema.csv, equipment_requirements.csv, excitation_plan.csv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]
2026-08-16 v0.3.0-E — Final experiment matrix
    [board_population_plan.csv, final_experiment_matrix.csv, specimen_registry.csv]
2026-08-16 Add preliminary PCB CAD generation and geometry validation
    [S0-0603.kicad_pcb, S90-0402.kicad_pcb, S90-0603.kicad_pcb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]
2026-08-16 v0.3.1 — PCB CAD & JLCPCB Fabrication Package
    [S0-0603.kicad_pcb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]
